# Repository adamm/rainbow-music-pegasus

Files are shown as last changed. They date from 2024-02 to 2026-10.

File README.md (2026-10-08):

# Rainbow Music Pegasus

Disclaimer: This work is a *work-in-progress*.  This project is still under
active development and is estimated to be completed _Spring 2027_.
What you see here is code that is largely incomplete, buggy, probably crashes,
and could catch fire. The PCB board is largely inefficient, expensive,
probably broken, and could catch fire.

## Description

Rainbow Music Pegasus is a combination 3D printed horse coupled with a PCB
with 10 or more RGB lights, microphone, and a MCU.  A
[Fast Fourier transform](https://en.wikipedia.org/wiki/Fast_Fourier_transform)
algorithm translates an audio signal from the microphone, which is displayed
as a flashing colour light display as the horse's wings.

The original design from the horse is from Stlflix, but its internals were
not adequate to support the PCB.  As a result I completely remapped all
vertices, and designed the internal mount to hold the PCB unit vertically.

## Design

The PCB features an ESP32-C3 MCU, a PUI Audio AOM-5024P-HD-MB-R electret
microphone, an OPA2322 dual amplifier with an MCP41050 digital potentiometer,
up to 24 WS2812B RGB LEDs, and an MCP73831 battery charging circuit.  The full schematic is in
[schematic.pdf](schematic.pdf) and the parts list is in [bom.csv](bom.csv).

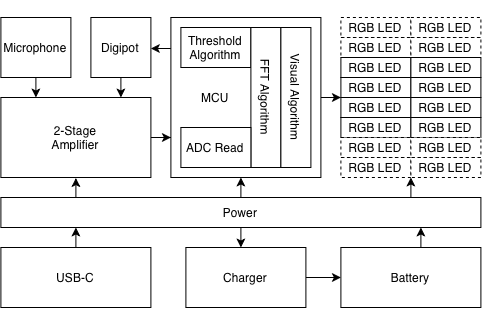
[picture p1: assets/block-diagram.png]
Block Diagram


[View on KiCanvas](https://kicanvas.org/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)

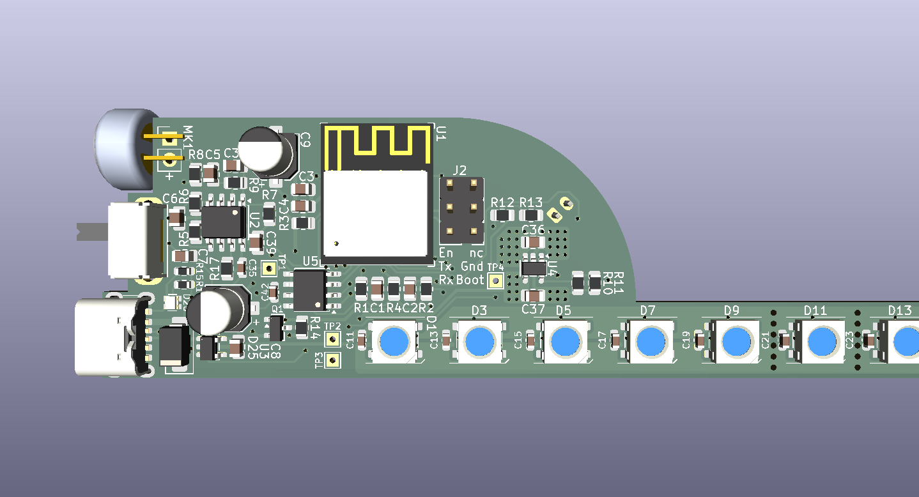
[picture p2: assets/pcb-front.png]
PCB v1.1 Front


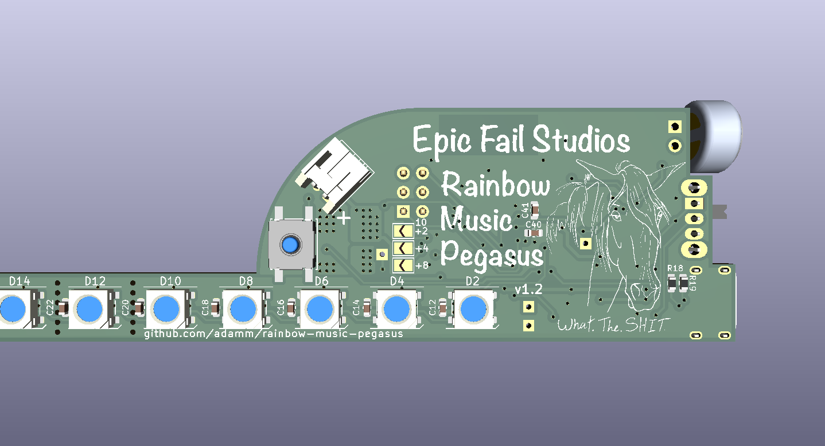
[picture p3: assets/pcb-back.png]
PCB v1.1 Back


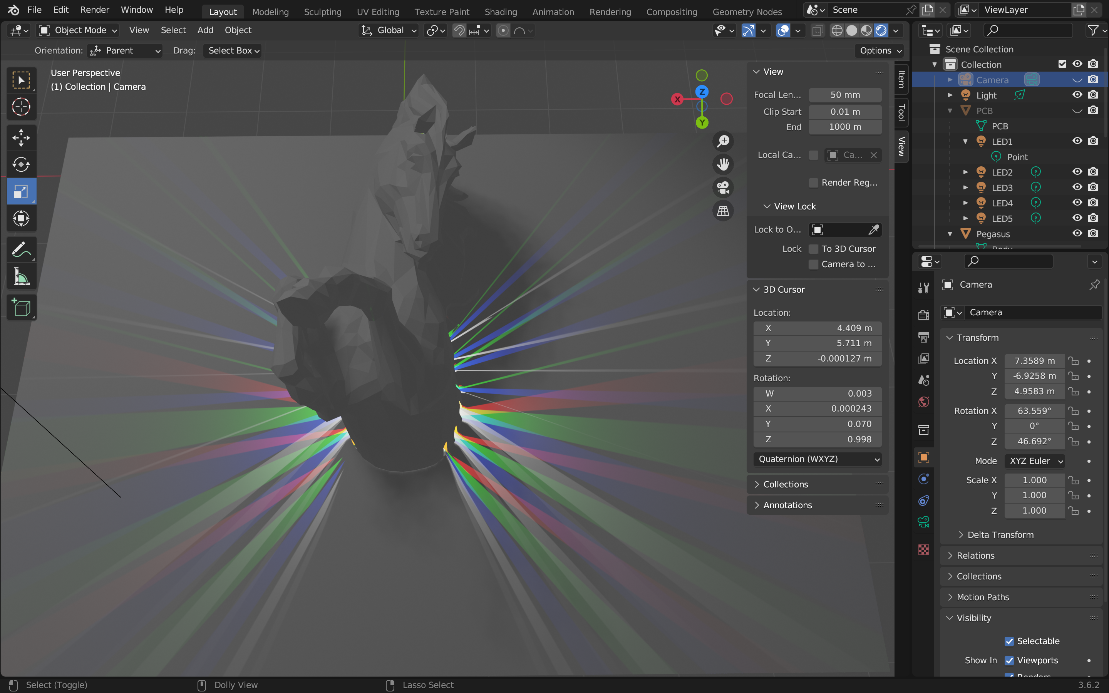
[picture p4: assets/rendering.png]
Rendering


## History

Version 1.0 of the rainbow-music-pegasus was completed March 2024.  A few
test units were sold at Breyer West show, but were never mass produced.
This version lacks wifi, bluetooth, and battery support.

Version 1.1 added a battery and charging module, battery status lights, and adjusting the position of the LEDs.

Version 1.2 is under active development. It will clean up the amp's stage-1
and digipot controlled stage-2, make use of the set-mode button, use USB-C
to charge, and other bug fixes. It is estimated to be completed Spring
2027.

## Battery

Use a single-cell (3.7V nominal) LiPo of 400mAh or larger, connected to the
JST PH connector J3.  The MCP73831 charges at a fixed 200mA (set by R10 and
R11), which keeps the charge rate at or below 0.5C for a 400mAh cell.  Larger
batteries are fine but take longer to charge: roughly 4 hours for 800mAh and
10 hours for 2000mAh.

When the battery runs low (under about 3.6V), the first light in each wing
blinks red every 3 seconds.  The rest of the light show carries on as usual.
The blinking stops once the battery is charging:

- **v1.1**: once charging brings the battery back over 3.7V.
- **v1.2**: within 10 seconds of plugging in USB.  While USB is plugged in,
  v1.2 measures the USB supply rather than the battery.

## Repository layout

| Path | Contents |
|---|---|
| [firmware/](firmware/) | ESP-IDF firmware for the ESP32-C3 (see its [README](firmware/README.md)) |
| [pcb/](pcb/) | KiCad project, 3D models and gerbers |
| [stl/](stl/) | Pegasus model (Blender, STL, 3MF), PCB model and SMT stencil mount (OpenSCAD) |
| [assets/](assets/) | Images used in this README |
| [schematic.pdf](schematic.pdf) | Exported schematic |
| [bom.csv](bom.csv) | Bill of materials |

Clone with submodules to get the Espressif KiCad libraries:

```sh
git clone --recurse-submodules https://github.com/adamm/rainbow-music-pegasus.git
```

## Building the firmware

The firmware uses ESP-IDF v5.x:

```sh
cd firmware
idf.py set-target esp32c3
idf.py build
idf.py -p <PORT> flash monitor
```

See [firmware/README.md](firmware/README.md) for the pin map, the LED-count
jumpers and how the audio pipeline works.

## Mic sensitivity

The microphone's sensitivity adjusts automatically.  If the sound is too
quiet it is turned up, and if it is so loud the wings stay at full
brightness it is turned down.  For 3 seconds after power-on, the wings will
appear to "flap" in white while the sensitivity settles to the room.  When
the device is moved between quiet and loud environments, it takes a few
seconds to catch up.

## Noisy rooms

The wings can show music over the sound of a crowd talking.  The pegasus keeps
learning each room's background sound, and lights up only for sound well
above it, such as the music's beats.  It follows a crowd as it gets louder
or quieter over several seconds.  Anything that holds steady, like a long
note, is learned too and fades away after about 20 seconds.  The music has
to be louder than the crowd, at least on its beats, to show.

## Set Mode

v1.1 has a new "Set Mode" button.  The intention is to flip between LED
animation modes, and to do a factory reset.

*Important*: Development of the button has not yet started but planned to be
ready Spring 2027 as v1.2.

## TODO

- [X] Release v1 for Breyer West 2024
- [X] Listen to music
- [X] Interpret music signal into the light show
- [X] Support a rechargable LiPo battery
- [X] Low battery warning
- [X] Replace USB-mini with USB-C for power
- [ ] Implement "Set Mode" button
- [ ] Add wifi support
- [ ] Add bluetooth support
- [ ] Release v1.2 for Calgary Makerfaire 2027
- [ ] Sync with nearby horses for an enhanced light show
- [ ] Control of colour modes and settings via Web Bluetooth
- [ ] Firmware updates over BLE

## License

See [LICENSE.md](LICENSE.md) (Apache 2.0).

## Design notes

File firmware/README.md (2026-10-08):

# Rainbow Music Pegasus Firmware

ESP-IDF firmware for the Rainbow Music Pegasus board.  It samples the
microphone, runs an FFT, and drives the WS2812B LEDs in the wings with the
result.

## Requirements

- [ESP-IDF](https://docs.espressif.com/projects/esp-idf/en/latest/esp32c3/get-started/)
  v5.x (the project was created with v5.5.1)
- Target: ESP32-C3 only.  Other targets fail to build: the original ESP32
  can't read the mic's ADC in DMA mode, and other models are untested.
- [esp-dsp](https://components.espressif.com/components/espressif/esp-dsp),
  fetched automatically by the IDF Component Manager

## Building and flashing

```sh
. $IDF_PATH/export.sh          # load the ESP-IDF environment
cd firmware
idf.py set-target esp32c3      # only needed the first time
idf.py build
idf.py -p <PORT> flash monitor
```

`<PORT>` is the board's USB serial device, e.g. `/dev/cu.usbmodem*` on macOS
or `/dev/ttyACM0` on Linux.  Exit the monitor with `Ctrl-]`.

## Unit tests

The unit tests in [`test/`](test/) run on your computer, not the board, so
they need only a C compiler and CMake 3.20 or later, not ESP-IDF or hardware.
They use the [Unity](https://github.com/ThrowTheSwitch/Unity) test framework,
which CMake downloads the first time.

```sh
cd firmware
cmake -S test -B test/build
cmake --build test/build
ctest --test-dir test/build --output-on-failure
```

Each `test/test_<module>.c` tests `main/<module>.c`.  The ESP-IDF calls the
firmware makes (GPIO, SPI, ADC, RMT, timer) go to the fakes in `test/fakes/`
instead.  A test uses them to set what the hardware reports, such as jumper
levels, ADC samples or the time, and to check what the firmware sent, such as
digipot wiper codes or LED bytes.  Run one test program, e.g.
`test/build/test_mic`, to see each of its tests by name.

The tests are built with AddressSanitizer and UndefinedBehaviorSanitizer, so
an out-of-bounds access fails a test instead of silently corrupting memory as
it would on the ESP32-C3.  Pass `-DSANITIZE=OFF` to CMake if your compiler
doesn't support them.

## How it works

1. **Configure** (`config.c`): read jumpers JP5–JP7 to decide how many LEDs
   are fitted, and pick the FFT size and sample rate from that and the
   [LED pattern](#led-patterns).
2. **Battery** (`battery.c`): take a first battery reading while the LEDs
   are still dark.
3. **Settle** (`main.c`): for 3 seconds a white "scanning" animation runs
   on the wings while the mic sensitivity and the background floor adjust to
   the room.
4. **Light show** (`main.c`, `leds.c`): forever, read the next half frame of
   mic samples and, with the half before it, remove DC, apply a Blackman
   window and FFT, adjust the mic sensitivity, learn each
   bin's background floor and keep only the sound well above it, apply a
   peak-and-decay filter, and send the bins to the LEDs.  Every 10 seconds,
   check the battery.

The ADC samples the mic in continuous (DMA) mode, at a rate set by the LED
count (see [Frequency range](#frequency-range)), so the sample timing is set
by hardware, not software delays, and other tasks such Bluetooth can't disturb
it.

Each frame overlaps the one before by half, so the LEDs update every half
frame: in pattern A every 3.2 ms with 10 LEDs, up to 7.7 ms with 24, and in
patterns B and C twice that.  Updating only once a frame sampled a held
note's level too slowly to follow quick changes in it, such as close partials
beating, and turned them into a slow flutter.

The driver hands over half a frame at a time and keeps only the newest: if
the FFT and LED update fall behind, older halves are dropped, so the lights
never lag the sound by more than a frame.  After a dropped half, the half kept
from the last frame no longer leads straight into the next, so the next frame
is read whole.

## LED count jumpers

The board supports 10 to 24 LEDs.  Closing a jumper pulls its GPIO low and
adds LEDs on top of the base 10:

| Jumper | GPIO | Adds |
|---|---|---|
| JP7 | 7 | +2 |
| JP6 | 6 | +4 |
| JP5 | 5 | +8 |

The total is capped at 24.  The FFT size follows the LED count: in pattern
A, 64 samples for up to 10 LEDs, 128 for up to 16, and 256 above that.
Patterns B and C use twice those sizes, 128, 256 and 512.

## LED patterns

The strip alternates between the wings: even LEDs (0, 2, 4, ...) are on the
right wing and odd ones on the left, so each pair of LEDs is the same place
on both wings, and LEDs 0 and 1 are nearest the ESP32.  Each of an LED's red,
green and blue channels shows how loud one FFT bin is.  `CONFIG_LEDS_PATTERN`
in [`main/config.h`](main/config.h) picks which bin each channel shows, at
compile time.  The default is C.

- **A**: each pair shows three bins.  The right LED shows them as green, red
  and blue, and the left LED with the channels rotated, as blue, green and
  red.  So the two wings are equally bright but differently coloured.  A tone
  in one bin is red, green or blue, a tone spread over two bins yellow, cyan
  or magenta, and a broad sound white.
- **B**: each channel shows its own bin, six per pair, lowest first: the
  right then the left LED's red, then their green, then their blue.  So each
  pair runs from red to blue, and the wings show alternate bins.
- **C**: each channel shows its own bin.  The lowest third of the bins light
  every LED's red in strip order, the middle third their green, and the top
  third their blue.  So each colour shows a third of the range along the
  wings: at the default top frequency, 0 to 781 Hz is red, 781 to 1563 Hz
  green, and 1563 to 2344 Hz blue.

So patterns B and C show twice as many bins as A, three per LED rather than
three per pair.  With 24 LEDs, the first pair shows:

| Pattern | Bins shown | LED 0 (right) red, green, blue | LED 1 (left) red, green, blue |
|---|---|---|---|
| A | 36 | bins 1, 0, 2 | bins 2, 1, 0 |
| B | 72 | bins 0, 2, 4 | bins 1, 3, 5 |
| C | 72 | bins 0, 24, 48 | bins 1, 25, 49 |

## Frequency range

Every board and pattern shows the same range, from 0 Hz up to
`CONFIG_LEDS_TOP_FREQ_HZ` (2344 Hz) in [`main/config.h`](main/config.h).  It's
shared equally between the bins the LEDs show, so more LEDs, and patterns B
and C, show it in finer steps.

The LEDs show the lowest LEDs * 3 / 2 bins in pattern A, and the lowest
LEDs * 3 in patterns B and C.  A bin is the sample rate divided by the FFT size
wide, so `config_init()` picks the sample rate that makes those bins end at the
top frequency:

    sample rate = FFT size * top frequency / bins shown

Patterns B and C show twice as many bins with twice the FFT size, so they
sample at the same rate as A.  Their bins are half as wide, but each frame
takes twice as long to sample, so the LEDs update half as often, every half
frame.

| LEDs | Sample rate | FFT size (A / B, C) | Bin width (A / B, C) | Frame (A / B, C) |
|---|---|---|---|---|
| 10 | 10.0 kHz | 64 / 128 | 156 / 78 Hz | 6.4 / 12.8 ms |
| 12 | 16.7 kHz | 128 / 256 | 130 / 65 Hz | 7.7 / 15.4 ms |
| 14 | 14.3 kHz | 128 / 256 | 112 / 56 Hz | 9.0 / 17.9 ms |
| 16 | 12.5 kHz | 128 / 256 | 98 / 49 Hz | 10.2 / 20.5 ms |
| 18 | 22.2 kHz | 256 / 512 | 87 / 43 Hz | 11.5 / 23.0 ms |
| 20 | 20.0 kHz | 256 / 512 | 78 / 39 Hz | 12.8 / 25.6 ms |
| 22 | 18.2 kHz | 256 / 512 | 71 / 36 Hz | 14.1 / 28.2 ms |
| 24 | 16.7 kHz | 256 / 512 | 65 / 33 Hz | 15.4 / 30.7 ms |

The sample rate is always more than four times the top frequency.  Sound
above half the sample rate folds back onto lower bins, and the mic's
anti-aliasing filters (R17 and C41 at 4.8 kHz, R9 and C38 at 10.6 kHz) cut
cymbals and other treble near 10 kHz by only about 10 dB.  A faster rate
folds back only higher sound, which the filters cut more.

Raise the top frequency to show more of the treble, or lower it to show more
detail in the bass.  Much above 4 kHz, the anti-aliasing filter dims the
highest LEDs.  The ADC can't sample faster than 83.3 kHz, which an 18-LED
board reaches at a top frequency of about 8.8 kHz.  The unit tests fail if any
board would need a rate outside the ADC's range.

## Pin map (ESP32-C3)

All pins are defined in [`main/config.h`](main/config.h).

| Function | GPIO | Direction |
|---|---|---|
| Battery (ADC1 channel 0) | 0 | Input |
| Button | 1 | Input |
| WS2812B data | 3 | Output |
| Microphone (ADC1 channel 4) | 4 | Input |
| LED-count jumpers | 5, 6, 7 | Input  |
| ESP32 Bootloader mode | 9 | Input |
| Digipot MOSI | 10 | Output |
| Digipot CS | 18 | Output |
| Digipot CLK | 19 | Output |
| Serial RXD / Code Upload | 20 | Input |
| Serial TXD / Activity Log | 21 | Output | 

## Source layout

| File | Purpose |
|---|---|
| `main.c` | Startup and the main sample → FFT → LED loop |
| `config.c/h` | Pin assignments, jumper-based LED count, LED pattern, FFT size, sample rate and top frequency |
| `mic.c/h` | Continuous (DMA) sampling of the microphone, with ADC calibration, and automatic mic sensitivity |
| `battery.c/h` | Battery voltage readings, smoothing, and the low-battery decision |
| `fft.c/h` | Fixed-point FFT of each frame: DC removal, Blackman window, FFT and bin levels in mV.  The ESP32-C3 has no FPU, so integer maths is much faster |
| `leds.c/h` | WS2812B output over RMT in each LED pattern, startup scanning animation, low-battery blink |
| `led_strip_encoder.c/h` | RMT encoder for WS2812B (from the ESP-IDF examples) |
| `digipot.c/h` | SPI driver for the MCP41050 digital potentiometer |

## Mic sensitivity

The MCP41050's B–W resistance is the feedback resistor of the second op-amp
stage (U2B), so the preamp gain is proportional to it.  Wiper code 00h is at
terminal B, so a higher wiper code means higher gain.  `mic.c` uses the
wiper code (0 to 255) directly as the sensitivity.

After every frame's FFT, `main.c` looks at the loudest bin the LEDs show and
tells `mic_sensitivity_update()` whether the frame was too loud or too quiet:

- If the brightest LED stays at full brightness, or the samples keep clipping
  near the ADC rails, for 50 ms, the sensitivity drops by a quarter (about
  -2.5 dB).
- If the loudest bin stays under a quarter of full brightness for 200 ms, the
  sensitivity rises by an eighth (about +1 dB).

The steps repeat while the condition lasts, so after moving to a louder or
quieter room the lights recover within a few seconds.

Each FFT bin is converted to millivolts at the ADC, so the LEDs behave the same
whatever the frame size.  Bins under `FFT_NOISE_FLOOR_MV` in `main.c` are
always dark, and bins at `FFT_FULL_SCALE_MV` light at full brightness.
Raising full scale makes the sensitivity settle higher, using more of the
ADC's range, as long as the signal doesn't clip.  The clipping limits and hold
times are `#define`s at the top of `mic.c`.

## Background sound

To show music over a noisy room, such as a crowd talking, `main.c` learns the
level of each FFT bin's background sound, its floor, and lights a bin only
once it's 12 dB (4 times) over that.  The floor is learned all the time,
and follows a crowd as it grows or thins.

- While a bin is louder than its floor, the floor rises by 1 dB a second.
  While it's quieter, the floor falls by 3 dB a second.  So the floor settles
  where the bin is quieter than it a quarter of the time.
- A crowd never goes quiet, so the floor sits on it.  Beats are loud for much
  less than three quarters of the time, so the floor stays under them and
  they stand out.
- Noise in a bin jumps around from frame to frame, and gets 12 dB over its
  quietest quarter in 1 to 2% of frames.  So a steady crowd still lights an
  LED dimly now and then.
- Anything that doesn't change is learned too, so a note held 20 dB over the
  threshold fades out in about 20 seconds.  The light show follows beats and
  changes more than steady sound.
- A bin's brightness runs from its threshold up to full scale, so music over
  a noisy room can still reach full brightness.  Beats 12 dB over a crowd's
  average level show at about a quarter of full brightness.
- In a quiet room the floor falls until the threshold is `FFT_NOISE_FLOOR_MV`,
  and stops there, so hiss stays dark and a new crowd is learned from there.
- During the 3-second settling period the floor learns 15 times faster, so it
  can climb 45 dB and the light show starts with the room already learned.
- When the mic sensitivity changes, `mic_sensitivity_update()` returns the
  change in gain, and the floor is scaled by it to stay in step with the
  sound.

Music has to be louder than the crowd, at least on its beats, to show: with
one microphone, sound no louder than the crowd can't be told apart from it.
Someone talking right next to the pegasus isn't learned either, because
speech has pauses.

The rates, margin and speed-up are the `FLOOR_` `#define`s at the top of
`main.c`.

## Battery level

R12 and R13 (100k each) halve the battery voltage at GPIO 0, so a full 4.2 V
battery reads 2.1 V.  `battery.c` averages 16 oneshot ADC readings and
doubles the result.

The mic and the battery are both on ADC1, which can sample continuously or
take oneshot readings but not both at once.  So `main.c` takes the first
reading at power-on, before the mic starts.  After that, every 10 seconds it
pauses the mic (`mic_pause()`), reads the battery and resumes the mic
(`mic_resume()`).  Resuming drops what the ADC recorded before the pause, and
the next frame is read whole, so this delays the next update by up to a frame
(15.4 ms in pattern A, 30.7 ms in B and C).

The voltage dips with the music as the LEDs draw current, so readings are
smoothed.  The smoothed voltage moves about two thirds of the way to a new
reading over 30 seconds.  The first reading is taken as is, because the LEDs
are still dark.  The battery is low once the smoothed voltage is under
3.6 V.  It stays low until the voltage is back over 3.7 V, so the warning
doesn't flicker on and off around 3.6 V.  The LEDs and ESP32-C3 run from a
3.3 V regulator, which starts to drop out with the battery under about 3.4 V.

While the battery is low, the first LED in each wing (the first pair on the
strip, nearest the ESP32) blinks red for a quarter of a second every 3
seconds.  It shows the music the rest of the time, and the other LEDs aren't
affected.  In pattern A the light show can't make both LEDs of a pair pure
red, so the blink can't be mistaken for music.  In patterns B and C it can,
when bass lights only the lowest two bins.

What GPIO 0 measures depends on the board:

- **v1.1**: the divider is wired straight to the battery, so it always reads
  the battery, even while USB charges it.  The warning stops once charging
  brings the battery back over 3.7 V.
- **v1.2**: the divider is after the power switch, so it doesn't drain the
  battery while the switch is off.  While USB is plugged in it reads the USB
  supply, about 4.6 V after D25, instead of the battery.  The warning stops at
  the next check after USB is plugged in.

The thresholds, smoothing time and number of samples are `#define`s at the
top of `battery.c`.  The check interval is in `main.c`, and the blink's
timing and brightness are in `leds.c`.

## Logs

Useful messages appear in the serial monitor:

- `config`: which jumpers are closed, the LED count, the LED pattern and how
  many bins it shows, the FFT size and the sample rate
- `battery`: each reading, e.g. `3712 mV, smoothed 3698 mV`, and when the
  battery becomes low or stops being low
- `main`: start and finish of the 3-second settling period, and each second,
  how many of the shown bins' background floors went up or down by more than
  0.5 dB, e.g. `adjusted the floor up on 3 bins and down on 1, of 15`.  Gain
  changes aren't counted, since `mic` logs those.  In a steady room most bins
  stay put; when a crowd grows or a note is held, they go up.
- `main`, each second of the light show: how many frames it processed, how
  long each lasts and how far apart they are (half a frame), how many halves
  of a frame the mic dropped because the frame before was still being
  processed, and how long a frame took to process, on average and at most.  The average is split into steps: reading the samples (converting them
  to mV, not waiting for them), the window (with removing DC), the FFT, the
  magnitudes, and the rest (the floor, the colours, sending them to the LEDs,
  the battery check and logging).  The light show keeps up while a frame takes
  less time to process than half a frame takes to record.  Once it doesn't,
  the mic drops halves of frames, and the LEDs miss that sound.
- `mic`: each sensitivity change, e.g. `too quiet, sensitivity 128 -> 144`

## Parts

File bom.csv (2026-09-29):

Reference | Value | Footprint | Description | Quantity
C1, C2, C4 | 0.1uF | Capacitor_SMD:C_0805_2012Metric |  | 3
C3 | 10uF | Capacitor_SMD:C_0805_2012Metric |  | 1
C5, C6, C8, C39 | 2.2uF | Capacitor_SMD:C_0805_2012Metric |  | 4
C7 | 1.0uF | Capacitor_SMD:C_0805_2012Metric |  | 1
C9, C10 | 220uF | Capacitor_SMD:CP_Elec_5x5.9 |  | 2
C11-C35, C40-C42 | 0.1uF | Capacitor_SMD:C_0603_1608Metric | Place C41 by GPIO4 | 28
C36, C37 | 4.7uF | Capacitor_SMD:C_0805_2012Metric |  | 2
C38 | 6.8nF C0G | Capacitor_SMD:C_0805_2012Metric |  | 1
D1-D24 | WS2812B | LED_SMD:LED_WS2812B_PLCC4_5.0x5.0mm_P3.2mm |  | 24
D25 | CDBA540 | Diode_SMD:D_SMA |  | 1
D26 | LTST-C195KGJRKT | Altivo:LTST-C195KGJRKT | LED dual red/green, 4-pin | 1
J1 | USB4125-GF-A-0190 | Altivo:USB_C_Receptacle_GCT_USB4125-xx-x-0190_6P_TopMnt_Horizontal | USB Power-Only 6P Type-C Receptacle connector | 1
J3 | S2B-PH-K-S | Connector_JST:JST_PH_S2B-PH-K_1x02_P2.00mm_Horizontal |  | 1
MK1 | AOM-5024P-HD-MB-R | Connector_PinHeader_2.54mm:PinHeader_1x02_P2.54mm_Vertical |  | 1
Q1 | DMG3415U | Package_TO_SOT_SMD:SOT-23 |  | 1
R1-R6, R10, R11 | 10k | Resistor_SMD:R_0805_2012Metric |  | 8
R7-R9 | 2.2k | Resistor_SMD:R_0805_2012Metric |  | 3
R12-R14 | 100k | Resistor_SMD:R_0805_2012Metric |  | 3
R15, R16 | 470 | Resistor_SMD:R_0603_1608Metric |  | 2
R17 | 330 | Resistor_SMD:R_0805_2012Metric |  | 1
R18, R19 | 5.1k | Resistor_SMD:R_0603_1608Metric |  | 2
SW1 | SW_SPDT | Button_Switch_THT:SW_Slide_SPDT_Angled_CK_OS102011MA1Q |  | 1
SW2 | EVQQ2 | Button_Switch_SMD:SW_SPST_EVQQ2 |  | 1
U1 | ESP32-C3-MINI-1 | PCM_Espressif:ESP32-C3-MINI-1 |  | 1
U2 | OPA2322 | Package_SO:SOIC-8_3.9x4.9mm_P1.27mm |  | 1
U3 | TLV75533PDBV | Package_TO_SOT_SMD:SOT-23-5 |  | 1
U4 | MCP73831-2-OT | Package_TO_SOT_SMD:SOT-23-5 |  | 1
U5 | MCP41050 | Package_SO:SOIC-8_3.9x4.9mm_P1.27mm |  | 1

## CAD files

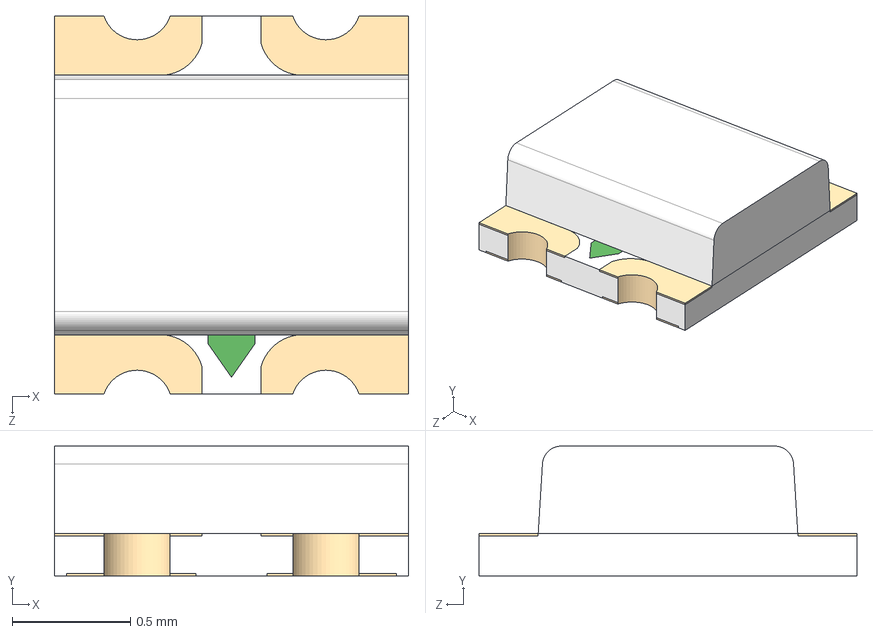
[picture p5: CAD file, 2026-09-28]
pcb/3d/LTST-C195KGJRKT.step
1.50 x 0.55 x 1.60 mm

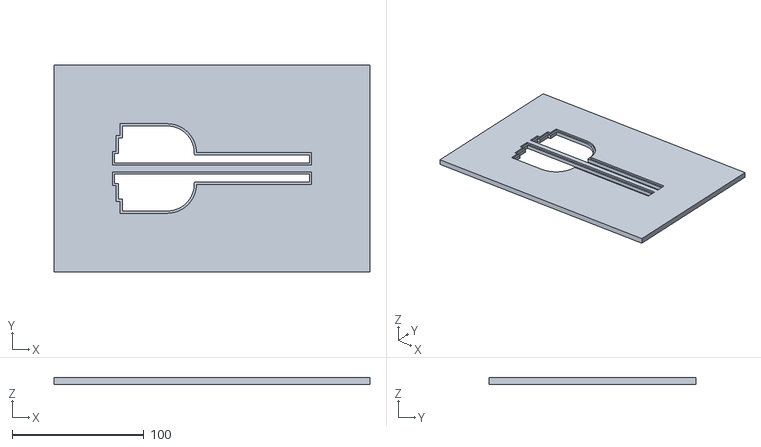
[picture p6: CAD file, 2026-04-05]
stl/stencil-mount.stl
240.0 x 157.0 x 5.00

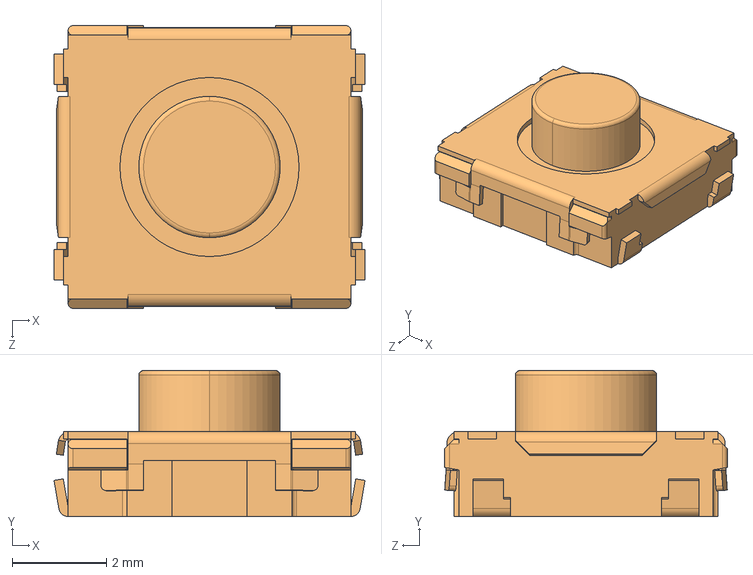
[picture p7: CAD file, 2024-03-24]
pcb/3d/evqq2-bfkpuy-03w_.step
6.60 x 3.10 x 6.00 mm

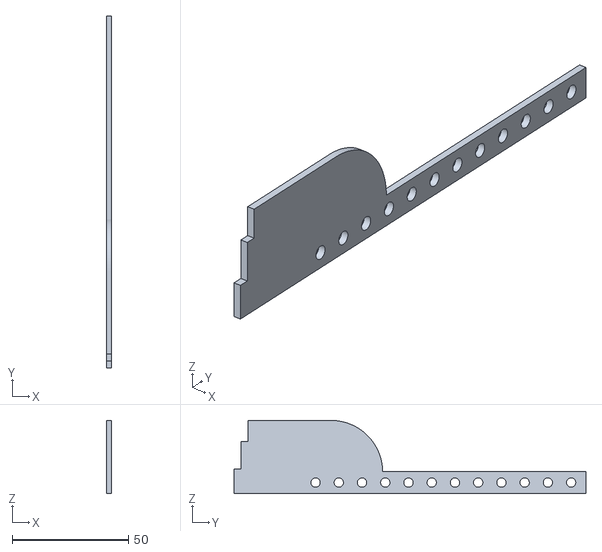
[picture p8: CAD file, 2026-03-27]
stl/pcb.stl
2.20 x 151.5 x 31.5

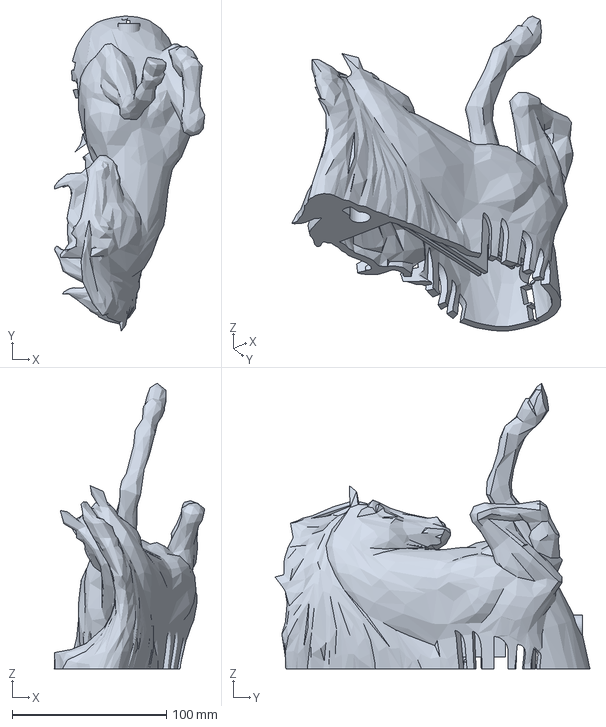
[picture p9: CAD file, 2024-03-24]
stl/pegasus.3mf
97.5 x 204.1 x 185.0 mm

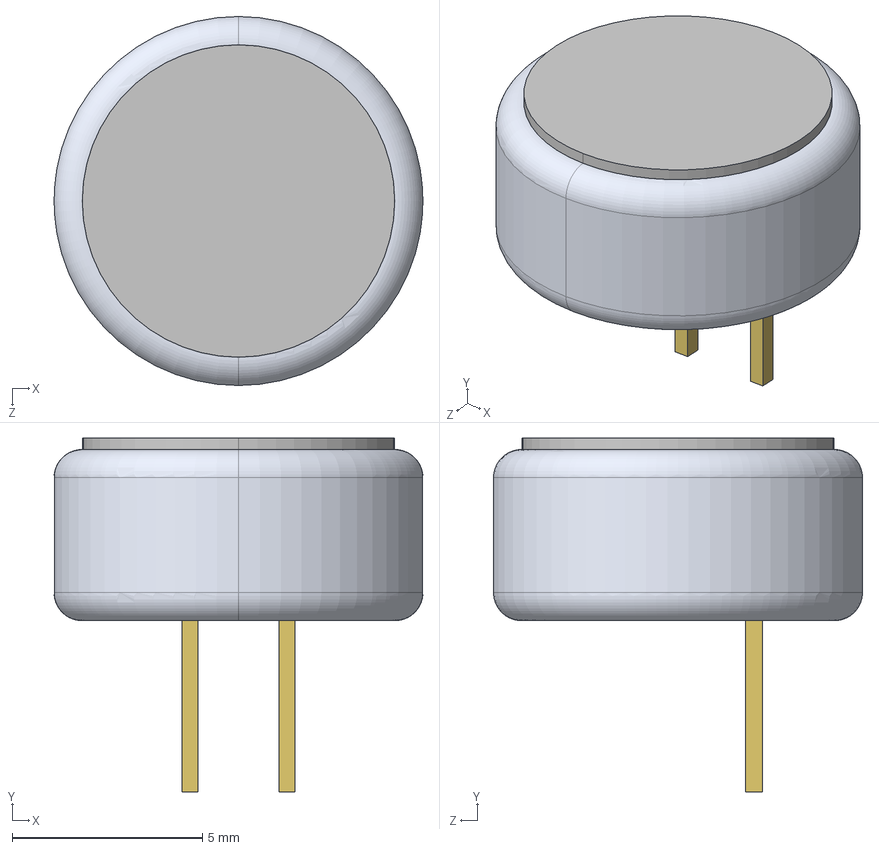
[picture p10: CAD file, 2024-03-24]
pcb/3d/CMA-4544PF-W.stp
9.69 x 9.30 x 9.70 mm

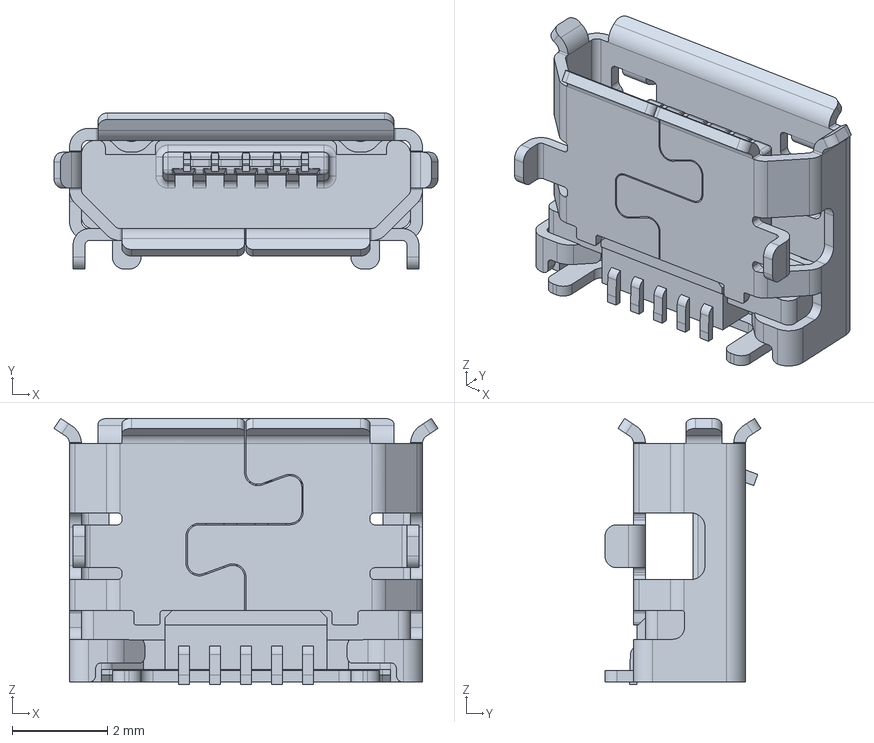
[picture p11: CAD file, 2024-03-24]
pcb/3d/10118194-0001LF.stp
8.05 x 3.27 x 5.58 mm

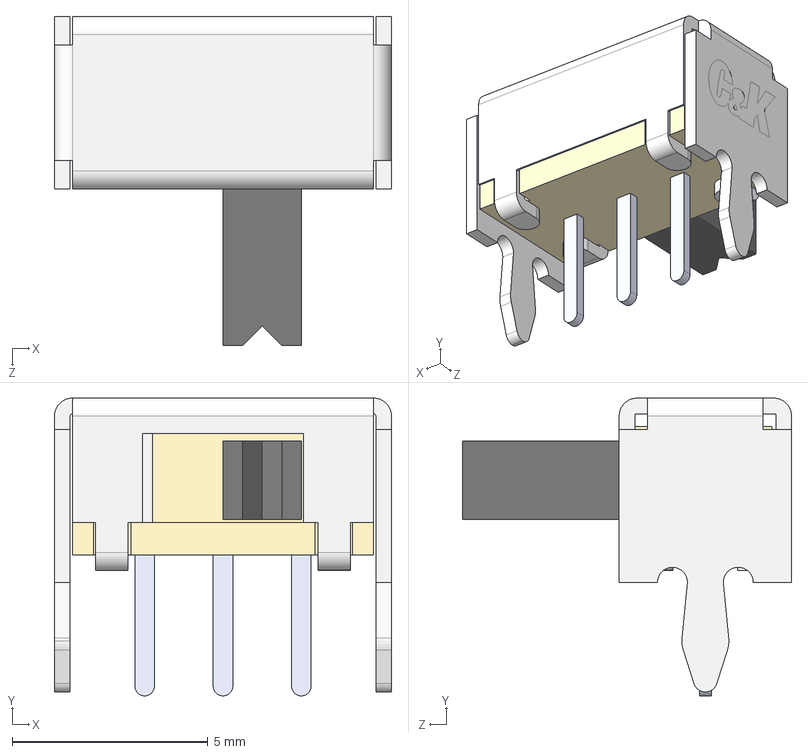
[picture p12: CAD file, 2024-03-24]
pcb/3d/OS102011MA1QN1.stp
8.60 x 7.60 x 8.40 mm
knob
cover
inside
pins

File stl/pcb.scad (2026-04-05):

$fn = 100;
pcb_w = 151;
pcb_l = 31;
pcb_h = 1.6;

rgb_x = 34.8525;
rgb_y = 4.5;
rgb_z = 1;
rgb_l = 9;
rgb_w = 10;
rgb_h = 2;

module microphone() {
    translate([20.0, pcb_l-3.0, 0.8])
        rotate([0,90,180])
            cylinder(27, 5.5, 5.5, false);
}

module switch() {
    translate([-4, 10.5, pcb_h-0.1])
        cube([13, 10.5, 5], false);
}

module usb() {
    translate([-4, 0.6, pcb_h-0.5])
        cube([13, 8.75, 3.5], false);
}

module led(x) {
    translate([rgb_x+x, rgb_y, rgb_z]) {
        cylinder(3, 2, 2, true);
    }
}

module holes(x) {
    translate([10.3333, pcb_l-6, -1]) {
        cylinder(4, 1.2, 1.2);
    }
    translate([37.8333, pcb_l-6, -1]) {
        cylinder(4, 1.2, 1.2);
    }
}

module pcb(draw_holes=true) {
    //translate([0, 0, -pcb_h/2])
    difference() {
        linear_extrude(height=pcb_h) {
            // Add 0.25mm to all ends to better align with
            // 3d printer tolerance
            offset(delta=+0.25) {
                polygon(points=[[0,0], [0, 10], [3, 10], [3, 22], [6,22], [6, pcb_l], [10, pcb_l],
                [41.5, pcb_l], [41.5, rgb_l], [pcb_w, rgb_l],
                [pcb_w, 0]
                ]);
                translate([41.5, 9, 0]) {
                    intersection() {
                        square(22);
                        circle(r=22);
                    }
                }
            }
        }
        if (draw_holes) {
            led(0);
            led(10);
            led(20);
            led(30);
            led(40);
            led(50);
            led(60);
            led(70);
            led(80);
            led(90);
            led(100);
            led(110);
        }
    }
}

rotate([90, 0, 90]) {
    union() {
        //microphone();
        //switch();
        //usb();
        //pcb(true);
    }
}

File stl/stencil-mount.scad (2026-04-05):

include <pcb.scad>;

margin_w = 30;
margin_l = 30;

stencil_w = 210;
stencil_l = 127;
stencil_h = 0.0;

board_w = stencil_w + margin_w;
board_l = stencil_l + margin_l;
board_h = 5.0;

board_x = pcb_w/2 - board_w/2;
board_y = -board_l/2;
board_z = 0;

stencil_x = -margin_w;
stencil_y = -(board_l/2) + margin_l/2;
stencil_z = board_h - stencil_h;

module negative_pcb(x, y, z) {
    translate([x, y, board_h-stencil_h-pcb_h]) //pcb(false);
        linear_extrude(height=board_h+3)
            projection(cut=true)
                pcb(false);
    translate([x, y, -0.01])
        linear_extrude(height=board_h+3)
            offset(delta=-1.75)
                projection(cut=true)
                    pcb(false);
}

module board() {
    difference() {
        translate([board_x, board_y, board_z])
            cube([board_w, board_l, board_h]);
        negative_pcb(0, 2.75, 0);
        mirror([0,1,0])
            negative_pcb(0, 2.75, 0);

        if (stencil_h > 0) {
            // Trim the stencil area
            translate([stencil_x, stencil_y, stencil_z])
                cube([stencil_w, stencil_l, stencil_h+4]);

            // Create a tab for lifting the stencil
            translate([stencil_w/2-pcb_w/2, stencil_y-margin_l, stencil_z])
               cube([stencil_w/4, stencil_l+margin_l*2, stencil_h+4]);
        }
    }
}

board();

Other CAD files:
stl/pegasus-extruded.blend
stl/pegasus.blend
stl/pegasus.stl

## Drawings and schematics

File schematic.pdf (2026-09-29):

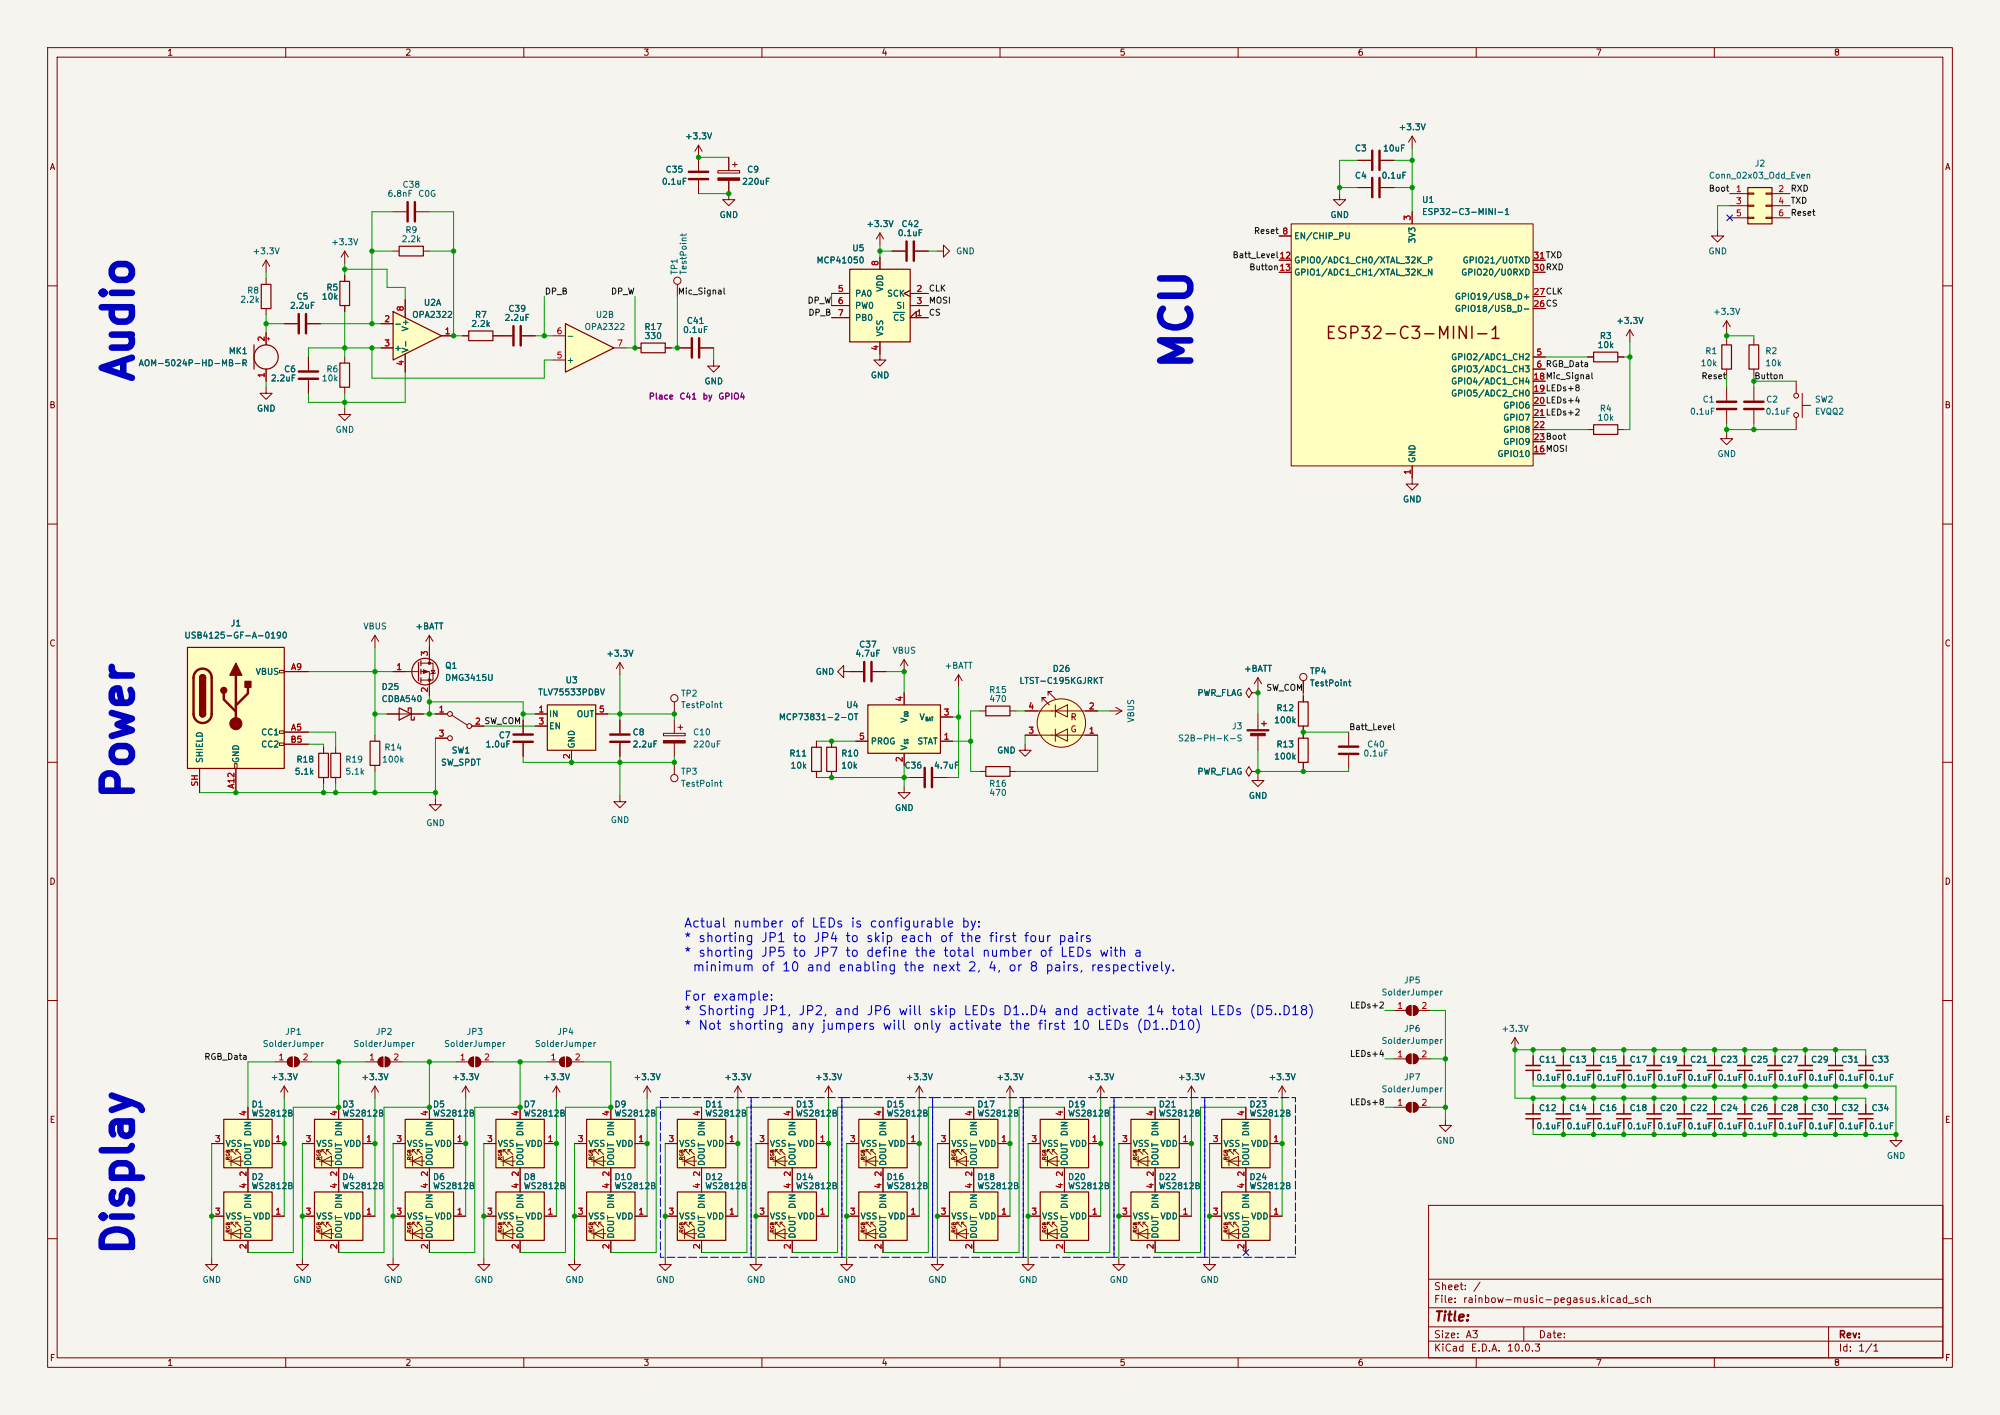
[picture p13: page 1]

* Not shorting any jumpers will only activate the first 10 LEDs (D1..D10) Power

Actual number of LEDs is configurable by:
* shorting JP1 to JP4 to skip each of the first four pairs
* shorting JP5 to JP7 to define the total number of LEDs with a minimum of 10 and enabling the next 2, 4, or 8 pairs, respectively.

For example:
* Shorting JP1, JP2, and JP6 will skip LEDs D1..D4 and activate 14 total LEDs (D5..D18)

4 D14 WS2812B +3.3V GND GND RGB VDD 1 DOUT 2

File: rainbow-music-pegasus.kicad_sch
Title:

Size: A3 | Rev:
KiCad E.D.A. 10.0.3 | Id: 1/1 | F Date:

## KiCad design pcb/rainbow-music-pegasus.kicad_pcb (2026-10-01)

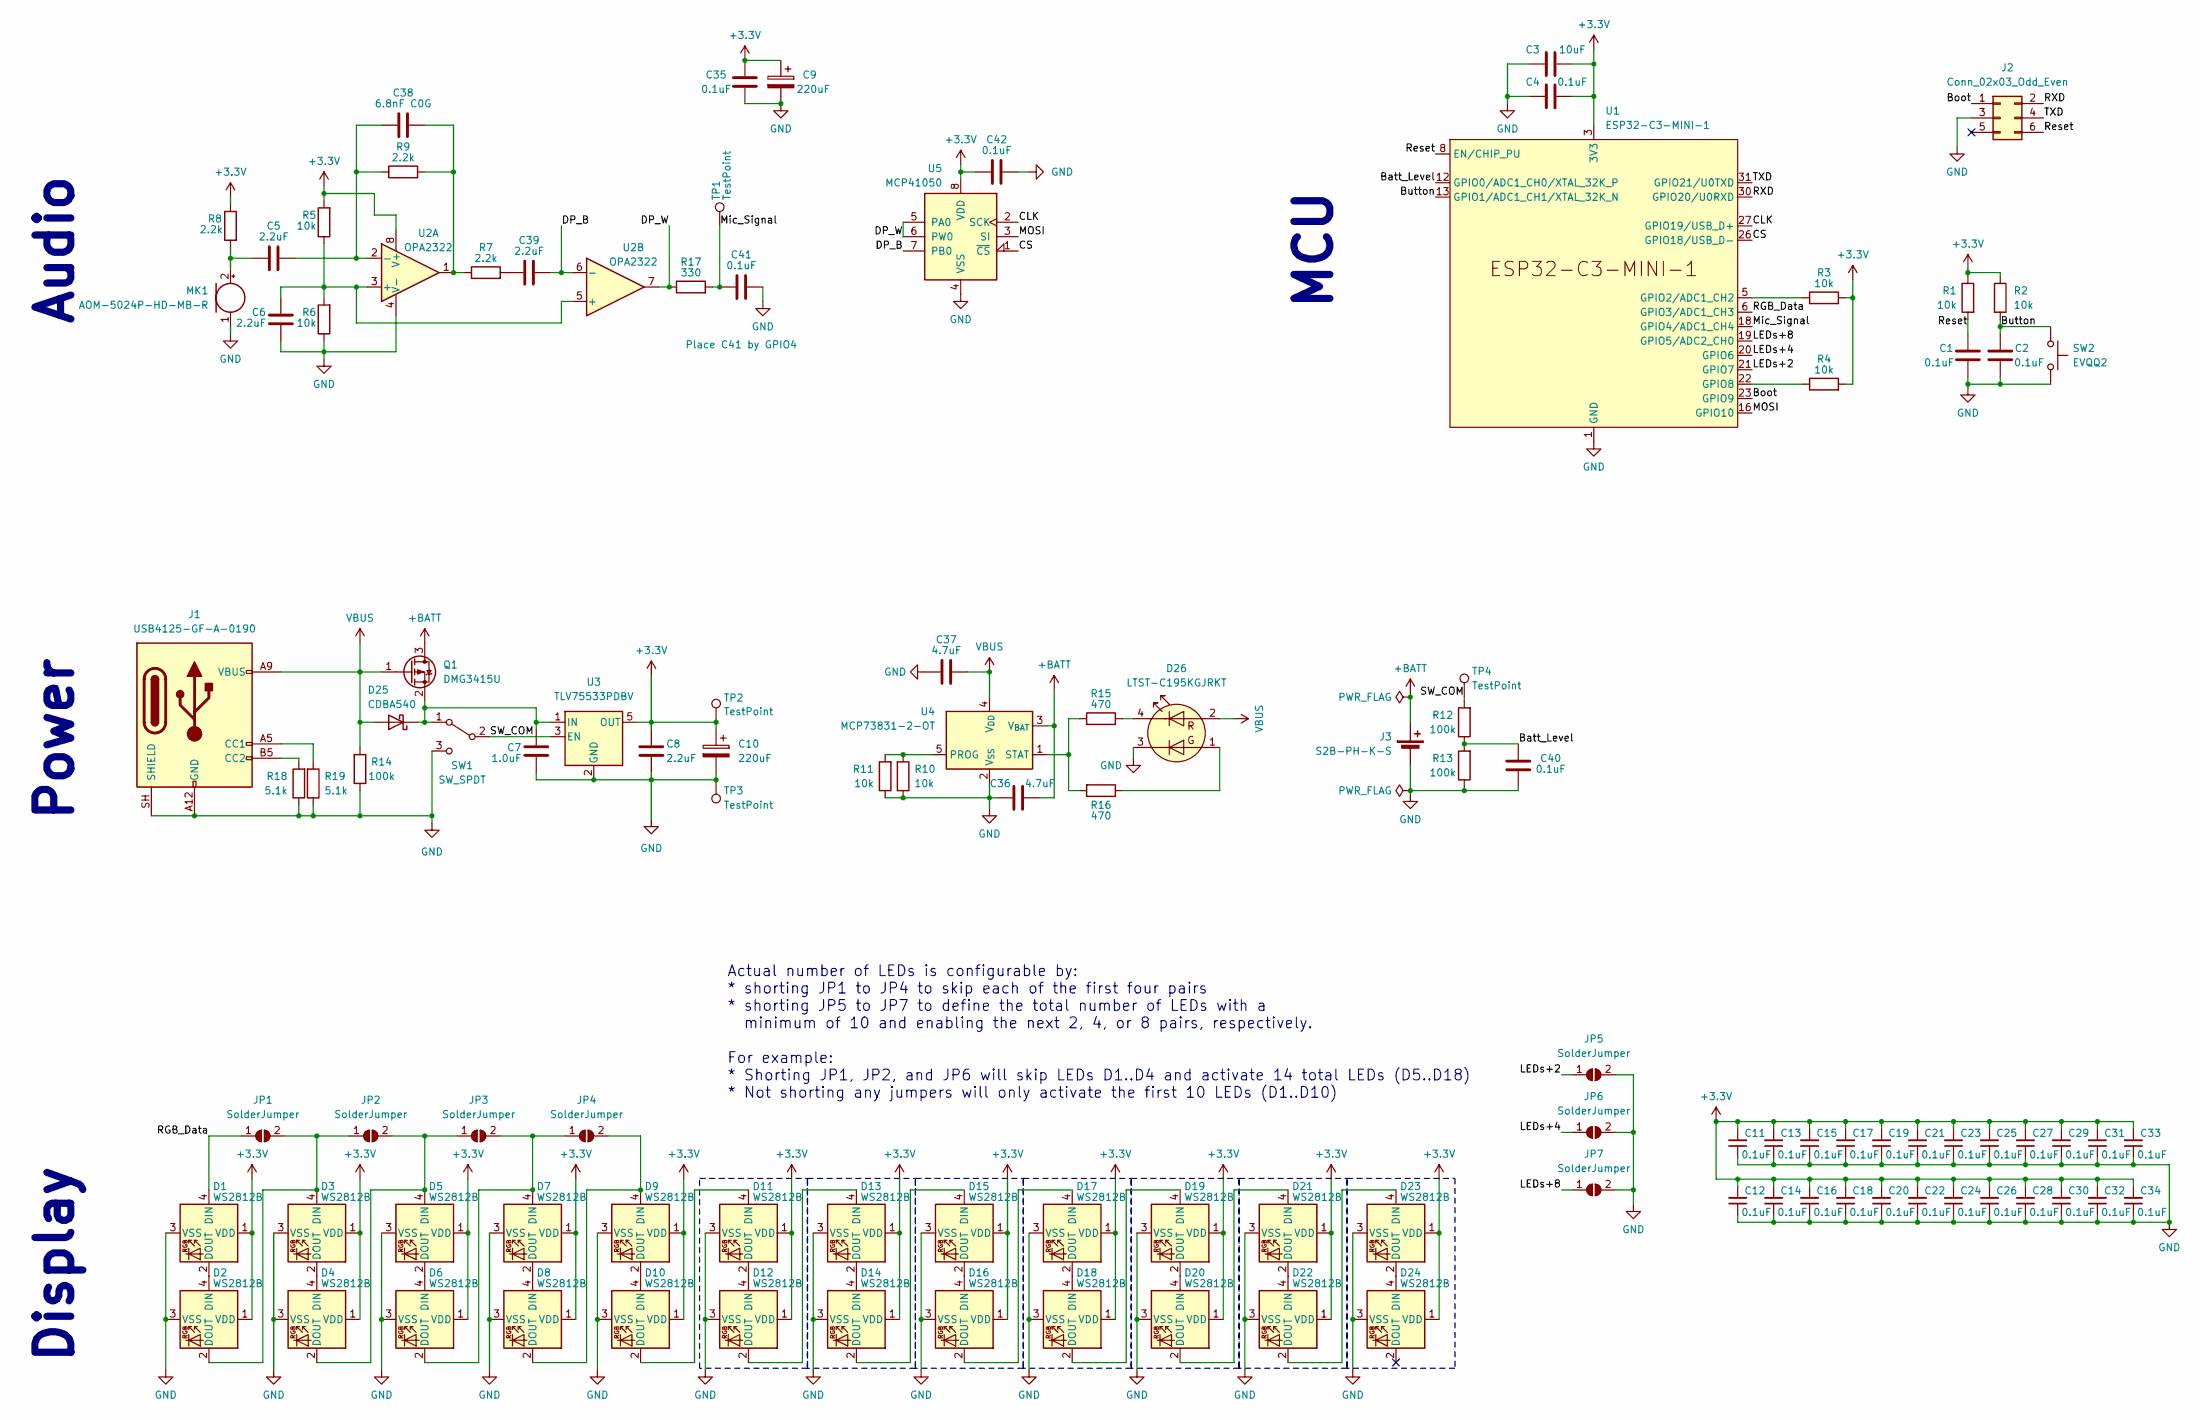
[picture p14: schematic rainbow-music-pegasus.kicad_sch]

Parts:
C1, C2, C4: 0.1uF; C_0805_2012Metric
C3: 10uF; C_0805_2012Metric
C5, C6, C8, C39: 2.2uF; C_0805_2012Metric
C7: 1.0uF; C_0805_2012Metric
C9, C10: 220uF; CP_Elec_5x5.9
C11, C12, C13, C14, C15, C16, C17, C18, C19, C20, C21, C22, C23, C24, C25, C26, C27, C28, C29, C30, C31, C32, C33, C34, C35, C40, C41, C42: 0.1uF; C_0603_1608Metric
C36, C37: 4.7uF; C_0805_2012Metric
C38: 6.8nF C0G; C_0805_2012Metric
D1, D2, D3, D4, D5, D6, D7, D8, D9, D10, D11, D12, D13, D14, D15, D16, D17, D18, D19, D20, D21, D22, D23, D24: WS2812B; LED_WS2812B_PLCC4_5.0x5.0mm_P3.2mm
D25: CDBA540; D_SMA
D26: LTST-C195KGJRKT
J1: USB4125-GF-A-0190; USB_C_Receptacle_GCT_USB4125-xx-x-0190_6P_TopMnt_Horizontal
J2: Conn_02x03_Odd_Even; PinHeader_2x03_P2.54mm_Vertical
J3: S2B-PH-K-S; JST_PH_S2B-PH-K_1x02_P2.00mm_Horizontal
JP1, JP2, JP3, JP4, JP5, JP6, JP7: SolderJumper; SolderJumper-2_P1.3mm_Open_TrianglePad1.0x1.5mm
MK1: AOM-5024P-HD-MB-R; PinHeader_1x02_P2.54mm_Vertical
Q1: DMG3415U; SOT-23
R1, R2, R3, R4, R5, R6, R10, R11: 10k; R_0805_2012Metric
R7, R8, R9: 2.2k; R_0805_2012Metric
R12, R13, R14: 100k; R_0805_2012Metric
R15, R16: 470; R_0603_1608Metric
R17: 330; R_0805_2012Metric
R18, R19: 5.1k; R_0603_1608Metric
SW1: SW_SPDT; SW_Slide_SPDT_Angled_CK_OS102011MA1Q
SW2: EVQQ2; SW_SPST_EVQQ2
TP1, TP2, TP3, TP4: TestPoint; TestPoint_THTPad_1.5x1.5mm_Drill0.7mm
U1: ESP32-C3-MINI-1
U2: OPA2322; SOIC-8_3.9x4.9mm_P1.27mm
U3: TLV75533PDBV; SOT-23-5
U4: MCP73831-2-OT; SOT-23-5
U5: MCP41050; SOIC-8_3.9x4.9mm_P1.27mm

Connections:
+3.3V: C3.2, C4.2, C8.2, C9.1, C10.1, C11.2, C12.2, C13.2, C14.2, C15.2, C16.2, C17.2, C18.2, C19.2, C20.2, C21.2, C22.2, C23.2, C24.2, C25.2, C26.2, C27.2, C28.2, C29.2, C30.2, C31.2, C32.2, C33.2, C34.2, C35.2, C42.1, D1.1 (VDD), D2.1 (VDD), D3.1 (VDD), D4.1 (VDD), D5.1 (VDD), D6.1 (VDD), D7.1 (VDD), D8.1 (VDD), D9.1 (VDD), D10.1 (VDD), D11.1 (VDD), D12.1 (VDD), D13.1 (VDD), D14.1 (VDD), D15.1 (VDD), D16.1 (VDD), D17.1 (VDD), D18.1 (VDD), D19.1 (VDD), D20.1 (VDD), D21.1 (VDD), D22.1 (VDD), D23.1 (VDD), D24.1 (VDD), R1.1, R2.1, R3.2, R4.2, R5.2, R8.1, TP2.1 (1_1), U1.3 (3V3), U2.8 (V+), U3.5 (OUT), U5.8 (VDD)
+BATT: C36.2, J3.1 (+), Q1.3 (D), U4.3 (V_{BAT})
/Batt_Level: C40.1, R12.1, R13.2, U1.12 (GPIO0/ADC1_CH0/XTAL_32K_P)
/Boot: J2.1, U1.23 (GPIO9)
/Button: C2.2, R2.2, SW2.1, U1.13 (GPIO1/ADC1_CH1/XTAL_32K_N)
/CLK: U1.27 (GPIO19/USB_D+), U5.2 (SCK)
/CS: U1.26 (GPIO18/USB_D-), U5.1 (~CS)
/DP_B: C39.2, U2.6 (-), U5.7 (PB0)
/DP_W: R17.1, U2.7, U5.5 (PA0), U5.6 (PW0)
/LEDs+2: JP5.1 (A), U1.21 (GPIO7)
/LEDs+4: JP6.1 (A), U1.20 (GPIO6)
/LEDs+8: JP7.1 (A), U1.19 (GPIO5/ADC2_CH0)
/MOSI: U1.16 (GPIO10), U5.3 (SI)
/Mic_Signal: C41.1, R17.2, TP1.1 (1_1), U1.18 (GPIO4/ADC1_CH4)
/RGB_Data: D1.4 (DIN), JP1.1 (A), U1.6 (GPIO3/ADC1_CH3)
/RXD: J2.2, U1.30 (GPIO20/U0RXD)
/Reset: C1.2, J2.6, R1.2, U1.8 (EN/CHIP_PU)
/SW_COM: R12.2, SW1.2 (B), TP4.1 (1_1), U3.3 (EN)
/TXD: J2.4, U1.31 (GPIO21/U0TXD)
GND: C1.1, C2.1, C3.1, C4.1, C6.1, C7.1, C8.1, C9.2, C10.2, C11.1, C12.1, C13.1, C14.1, C15.1, C16.1, C17.1, C18.1, C19.1, C20.1, C21.1, C22.1, C23.1, C24.1, C25.1, C26.1, C27.1, C28.1, C29.1, C30.1, C31.1, C32.1, C33.1, C34.1, C35.1, C36.1, C37.1, C40.2, C41.2, C42.2, D1.3 (VSS), D2.3 (VSS), D3.3 (VSS), D4.3 (VSS), D5.3 (VSS), D6.3 (VSS), D7.3 (VSS), D8.3 (VSS), D9.3 (VSS), D10.3 (VSS), D11.3 (VSS), D12.3 (VSS), D13.3 (VSS), D14.3 (VSS), D15.3 (VSS), D16.3 (VSS), D17.3 (VSS), D18.3 (VSS), D19.3 (VSS), D20.3 (VSS), D21.3 (VSS), D22.3 (VSS), D23.3 (VSS), D24.3 (VSS), D26.3 (K2), J1.A12 (GND), J1.B12 (GND), J1.SH (SHIELD), J2.3, J3.2 (-), JP5.2 (B), JP6.2 (B), JP7.2 (B), MK1.1 (-), R6.1, R10.1, R11.1, R13.1, R14.1, R18.1, R19.1, SW1.3 (C), SW2.2, TP3.1 (1_1), U1.1 (GND), U1.2 (GND), U1.11 (GND), U1.14 (GND), U1.36 (GND), U1.37 (GND), U1.38 (GND), U1.39 (GND), U1.40 (GND), U1.41 (GND), U1.42 (GND), U1.43 (GND), U1.44 (GND), U1.45 (GND), U1.46 (GND), U1.47 (GND), U1.48 (GND), U1.49 (GND), U1.50 (GND), U1.51 (GND), U1.52 (GND), U1.53 (GND), U2.4 (V-), U3.2 (GND), U4.2 (V_{SS}), U5.4 (VSS)
unnamed: C38.1, R7.1, R9.2, U2.1
unnamed: C39.1, R7.2
unnamed: D1.2 (DOUT), D2.4 (DIN)
unnamed: D2.2 (DOUT), D3.4 (DIN), JP1.2 (B), JP2.1 (A)
unnamed: D3.2 (DOUT), D4.4 (DIN)
unnamed: D4.2 (DOUT), D5.4 (DIN), JP2.2 (B), JP3.1 (A)
unnamed: D5.2 (DOUT), D6.4 (DIN)
unnamed: D6.2 (DOUT), D7.4 (DIN), JP3.2 (B), JP4.1 (A)
unnamed: D7.2 (DOUT), D8.4 (DIN)
unnamed: D8.2 (DOUT), D9.4 (DIN), JP4.2 (B)
unnamed: D9.2 (DOUT), D10.4 (DIN)
unnamed: D10.2 (DOUT), D11.4 (DIN)
unnamed: D11.2 (DOUT), D12.4 (DIN)
unnamed: D12.2 (DOUT), D13.4 (DIN)
unnamed: D13.2 (DOUT), D14.4 (DIN)
unnamed: D14.2 (DOUT), D15.4 (DIN)
unnamed: D15.2 (DOUT), D16.4 (DIN)
unnamed: D16.2 (DOUT), D17.4 (DIN)
unnamed: D17.2 (DOUT), D18.4 (DIN)
unnamed: D18.2 (DOUT), D19.4 (DIN)
unnamed: D19.2 (DOUT), D20.4 (DIN)
unnamed: D20.2 (DOUT), D21.4 (DIN)
unnamed: D21.2 (DOUT), D22.4 (DIN)
unnamed: D22.2 (DOUT), D23.4 (DIN)
unnamed: D23.2 (DOUT), D24.4 (DIN)
unnamed: C7.2, D25.1 (K), Q1.2 (S), SW1.1 (A), U3.1 (IN)
unnamed: D26.1 (A2), R16.1
unnamed: D26.4 (K1), R15.2
unnamed: J1.A5 (CC1), R19.2
unnamed: J1.B5 (CC2), R18.2
unnamed: C5.1, MK1.2 (+), R8.2
unnamed: R3.1, U1.5 (GPIO2/ADC1_CH2)
unnamed: R4.1, U1.22 (GPIO8)
unnamed: C6.2, R5.1, R6.2, U2.3 (+), U2.5 (+)
unnamed: C5.2, C38.2, R9.1, U2.2 (-)
unnamed: R10.2, R11.2, U4.5 (PROG)
unnamed: R15.1, R16.2, U4.1 (STAT)
VBUS: C37.2, D25.2 (A), D26.2 (A1), J1.A9 (VBUS), J1.B9 (VBUS), Q1.1 (G), R14.2, U4.4 (V_{DD})

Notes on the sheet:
Display
Actual number of LEDs is configurable by: * shorting JP1 to JP4 to skip each of the first four pairs * shorting JP5 to JP7 to define the total number of LEDs with a minimum of 10 and enabling the next 2, 4, or 8 pairs, respectively. For example: * Shorting JP1, JP2, and JP6 will skip LEDs D1..D4 an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
Audio
MCU
Power

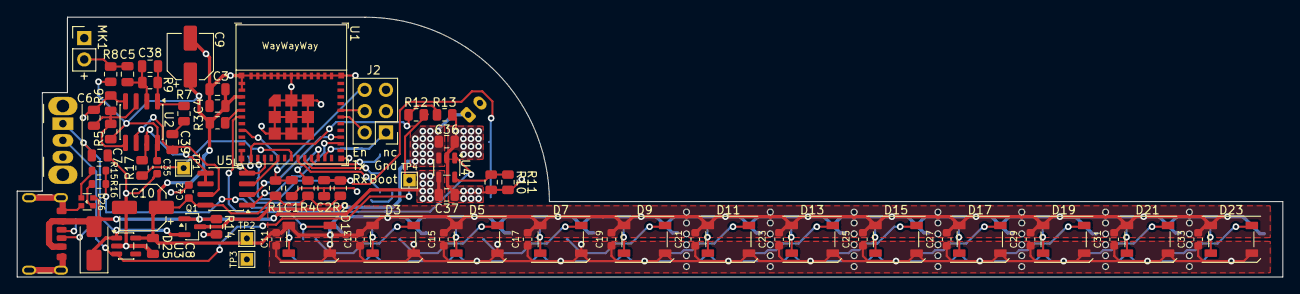
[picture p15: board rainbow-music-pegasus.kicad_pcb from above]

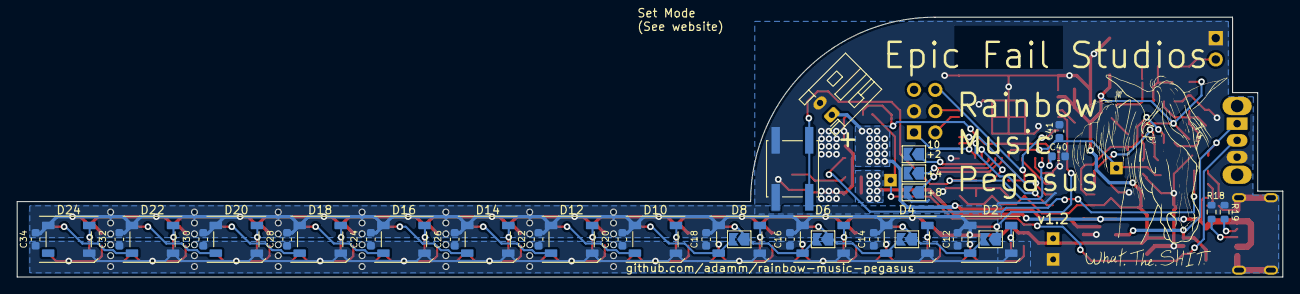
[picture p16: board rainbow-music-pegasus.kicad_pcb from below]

Board: 2 copper layers, 151.0 x 31.0 mm, 110 parts (37 on the bottom side), 58 nets.

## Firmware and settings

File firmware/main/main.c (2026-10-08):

/*
 * SPDX-FileCopyrightText: 2022-2023 Espressif Systems (Shanghai) CO LTD
 *
 * SPDX-License-Identifier: Apache-2.0
 */
#include <stdio.h>
#include <stdlib.h>
#include <string.h>
#include <math.h>

#include "esp_dsp.h"
#include "esp_log.h"
#include "esp_system.h"
#include "esp_timer.h"
#include "freertos/FreeRTOS.h"
#include "freertos/task.h"
#include "soc/soc_caps.h"


#include "battery.h"
#include "config.h"
#include "digipot.h"
#include "fft.h"
#include "leds.h"
#include "mic.h"

const static char *TAG = "main";



#define N_SAMPLES _config_total_samples
// Each frame overlaps the one before by half, so the LEDs update every half
// frame, every 15.4 ms with 24 LEDs in pattern C.  Updating only once a frame
// sampled a held note's level too slowly to follow quick changes in it, such
// as close partials beating, and turned them into a slow flutter.
#define N_HOP (N_SAMPLES / 2)
// leds_display() only shows the lowest bins, three per pair of LEDs in pattern
// A and three per LED in the others.
#define N_DISPLAYED_BINS config_displayed_bins()

// Each bin is converted to the amplitude, in mV at the ADC, of a sine wave that
// would produce it, so the LEDs behave the same whatever the frame size.  Bins
// under the noise floor stay dark so amp and ADC hiss doesn't flicker the LEDs,
// and bins at full scale light their LED at full brightness.  Full scale is well
// under the ADC's ~750 mV of headroom, leaving room for peaks across many bins.
#define FFT_NOISE_FLOOR_MV 8.5f
#define FFT_FULL_SCALE_MV  150.0f

#define DB_TO_RATIO(db) powf(10, (db) / 20)

// Each bin's floor is the level of the room's background sound in it, such as a
// crowd talking, and the bin lights only once it's FLOOR_MARGIN_DB over that.
// The floor rises slowly while the bin is louder than it and falls three times
// as fast while it's quieter, so it settles where the bin is quieter than it a
// quarter of the time.  A crowd never goes quiet, so the floor sits on it, but
// beats are loud for much less than three quarters of the time and stand out.
// Anything held steady is learned too, so a note held 20 dB over the threshold
// fades out in about 20 seconds.  Noise in a bin jumps around from frame to
// frame, and reaches the margin over its quietest quarter in only 1 to 2% of
// frames.
#define FLOOR_RISE_DB_PER_S  1.0f
#define FLOOR_FALL_DB_PER_S  3.0f
#define FLOOR_MARGIN_DB      12.0f
// Below this the threshold would be under FFT_NOISE_FLOOR_MV anyway, so the
// floor stops here, ready to learn a crowd from where it starts to matter.
#define FLOOR_LOWEST_MV      (FFT_NOISE_FLOOR_MV / DB_TO_RATIO(FLOOR_MARGIN_DB))
// While the mic settles at power-on, the floor learns the room this many times
// faster, so it can climb 45 dB in the 3 seconds.
#define FLOOR_SETTLE_SPEEDUP 15.0f
// How often to log how many of the shown bins' floors went up or down, to watch
// them learn a room.  A floor counts as moved once it's changed by more than
// FLOOR_LOG_MOVED_DB since the last log, so a settled floor's jitter doesn't.
#define FLOOR_LOG_US         1000000
#define FLOOR_LOG_MOVED_DB   0.5f

// Once the sound in a bin drops, its LED fades to about a third (1/e) of its
// brightness in this time.  Fading by a fraction rather than a fixed step keeps
// dim LEDs from blinking out, so quiet music doesn't flicker.  Rises show
// immediately.
#define LED_DECAY_US 150000

// How often to check the battery during the light show.  Each check delays the
// next frame by up to a frame, which is too brief and rare to notice.
#define BATTERY_CHECK_US 10000000

// How often to log how long the light show takes to process a frame, and how
// many hops of new samples the mic dropped because the frame before was still
// being processed.  The loop keeps up while processing a frame takes less time
// than recording a hop.
#define FRAME_LOG_US         1000000

// Each shown bin's floor at the last floor log, and when that was, 0 for never.
static float floor_logged[CONFIG_MAX_LEDS * 3];
static int64_t floor_logged_us = 0;

// Whether the samples kept from the last frame are out of date, so the next
// frame must be read whole: at power-on, and after the mic pauses.  And
// mic_frames_dropped() after the last frame was read, as a dropped hop leaves
// a gap after them too.
static bool frame_stale = true;
static uint32_t frame_dropped = 0;

// The time spent on each step of the frames since the last frame log, in µs.
static struct {
    int frames;
    int64_t read_us;       // converting samples to mV, not waiting for them
    int64_t window_us;     // removing DC and applying the window
    int64_t fft_us;
    int64_t magnitude_us;
    int64_t busy_us;       // the whole frame, except waiting for samples
    int64_t max_busy_us;
    int64_t frame_end_us;  // when the last frame ended
    int64_t waited_us;     // mic_time_waited_us() then
    uint32_t dropped;      // mic_frames_dropped() at the last log
    int64_t logged_us;
} frame_stats;


// Add the time since *since to *total_us, and move *since on to now.
static void time_step(int64_t* total_us, int64_t* since)
{
    int64_t now = esp_timer_get_time();
    *total_us += now - *since;
    *since = now;
}


// Read a hop of samples from the mic into the end of the frame in voltages,
// after the newest samples of the last frame, and put the shown bins' levels,
// in mV, in vReal.  The bins past them are left as they were, as nothing uses
// them.
// Then let the mic adjust its sensitivity to fit the LEDs: too loud if the ADC
// clipped or the brightest LED would be at full brightness, too quiet if the
// loudest bin is under a quarter of that.  The 12 dB gap between the two is
// several sensitivity steps wide, so the gain settles instead of hunting.
// Returns how much the mic's gain changed, as a ratio.
static float read_spectrum(int* voltages, float* vReal)
{
    float peak = 0;
    int64_t step_start = esp_timer_get_time();
    int64_t waited = mic_time_waited_us();
    bool clipped = false;
    if (frame_stale || mic_frames_dropped() != frame_dropped) {
        for (int start = 0; start < N_SAMPLES; start += N_HOP)
            clipped |= mic_read_frame(voltages + start, N_HOP);
        frame_stale = false;
    } else {
        memmove(voltages, voltages + N_HOP, (N_SAMPLES - N_HOP) * sizeof(int));
        clipped = mic_read_frame(voltages + N_SAMPLES - N_HOP, N_HOP);
    }
    frame_dropped = mic_frames_dropped();
    frame_stats.read_us -= mic_time_waited_us() - waited;
    time_step(&frame_stats.read_us, &step_start);

    fft_load(voltages);
    time_step(&frame_stats.window_us, &step_start);
    fft_compute();
    time_step(&frame_stats.fft_us, &step_start);
    int bins = N_DISPLAYED_BINS;
    fft_magnitudes(vReal, bins);
    time_step(&frame_stats.magnitude_us, &step_start);

    for (int i = 0; i < bins; i++) {
        if (vReal[i] > peak)
            peak = vReal[i];
    }

    return mic_sensitivity_update(clipped || peak >= FFT_FULL_SCALE_MV, peak < FFT_FULL_SCALE_MV / 4);
}


// Learn each shown bin's floor in vFloor from this frame's bins in vReal, in
// mV, elapsed_us after the last frame, and speedup times faster than normal.
// Then follow the mic's gain, which changes by gain_change within a frame or
// so.
static void track_floor(const float* vReal, float* vFloor, float gain_change, int64_t elapsed_us, float speedup)
{
    float seconds = speedup * elapsed_us / 1e6f;
    float rise = DB_TO_RATIO(FLOOR_RISE_DB_PER_S * seconds) * gain_change;
    float fall = DB_TO_RATIO(-FLOOR_FALL_DB_PER_S * seconds) * gain_change;
    int bins = N_DISPLAYED_BINS;

    for (int i = 0; i < bins; i++) {
        vFloor[i] *= vReal[i] > vFloor[i] ? rise : fall;
        if (vFloor[i] < FLOOR_LOWEST_MV)
            vFloor[i] = FLOOR_LOWEST_MV;
    }
}


// Every FLOOR_LOG_US, log how many of the shown bins' floors went up or down.
// Leave out the mic's gain changes, gain_change since the last frame, which
// mic.c logs itself.
static void log_floor(const float* vFloor, float gain_change, int64_t now)
{
    for (int i = 0; i < N_DISPLAYED_BINS; i++)
        floor_logged[i] *= gain_change;

    if (floor_logged_us != 0 && now - floor_logged_us < FLOOR_LOG_US)
        return;

    if (floor_logged_us != 0) {
        float moved = DB_TO_RATIO(FLOOR_LOG_MOVED_DB);
        int up = 0, down = 0;

        for (int i = 0; i < N_DISPLAYED_BINS; i++) {
            if (vFloor[i] > floor_logged[i] * moved)
                up++;
            else if (vFloor[i] < floor_logged[i] / moved)
                down++;
        }
        ESP_LOGI(TAG, "adjusted the floor up on %d bins and down on %d, of %d", up, down, N_DISPLAYED_BINS);
    }

    memcpy(floor_logged, vFloor, N_DISPLAYED_BINS * sizeof(float));
    floor_logged_us = now;
}


// Start timing the light show's frames, from `now`.
static void start_frame_log(int64_t now)
{
    memset(&frame_stats, 0, sizeof(frame_stats));
    frame_stats.frame_end_us = now;
    frame_stats.waited_us = mic_time_waited_us();
    frame_stats.dropped = mic_frames_dropped();
    frame_stats.logged_us = now;
}


// The average of total_us over the frames since the last frame log, in ms.
static float ms_per_frame(int64_t total_us)
{
    return total_us / 1000.0f / frame_stats.frames;
}


// Count a frame of the light show that ended at `now`.  Every FRAME_LOG_US,
// log how long frames took to process, step by step, and how many hops the
// mic dropped.  The rest is the floor, the colours, sending them to the LEDs, the
// battery check and logging.
static void log_frames(int64_t now)
{
    int64_t waited = mic_time_waited_us();
    int64_t busy = now - frame_stats.frame_end_us - (waited - frame_stats.waited_us);

    frame_stats.frames++;
    frame_stats.busy_us += busy;
    if (busy > frame_stats.max_busy_us)
        frame_stats.max_busy_us = busy;
    frame_stats.frame_end_us = now;
    frame_stats.waited_us = waited;

    if (now - frame_stats.logged_us < FRAME_LOG_US)
        return;

    uint32_t dropped = mic_frames_dropped();
    int64_t steps_us = frame_stats.read_us + frame_stats.window_us + frame_stats.fft_us + frame_stats.magnitude_us;
    ESP_LOGI(TAG, "%d frames of %.1f ms, %.1f ms apart, %d dropped, %.1f ms busy each (max %.1f): "
             "read %.1f, window %.1f, FFT %.1f, magnitude %.1f, rest %.1f",
             frame_stats.frames, N_SAMPLES * 1000.0f / _config_sample_freq_hz,
             N_HOP * 1000.0f / _config_sample_freq_hz, (int)(dropped - frame_stats.dropped),
             ms_per_frame(frame_stats.busy_us), frame_stats.max_busy_us / 1000.0f,
             ms_per_frame(frame_stats.read_us), ms_per_frame(frame_stats.window_us),
             ms_per_frame(frame_stats.fft_us), ms_per_frame(frame_stats.magnitude_us),
             ms_per_frame(frame_stats.busy_us - steps_us));

    start_frame_log(now);
}


// Replace each shown bin in vReal with its LED brightness, and set colours
// from it.  A bin lights once it's FLOOR_MARGIN_DB over its floor in vFloor,
// and never under FFT_NOISE_FLOOR_MV.  vDecay holds each LED's brightness from
// the last frame, elapsed_us ago: louder bins show immediately, and quieter
// ones fade from there.
static void spectrum_to_colours(float* vReal, const float* vFloor, float* vDecay, uint8_t* colours, int64_t elapsed_us)
{
    float decay = expf(-(float)elapsed_us / LED_DECAY_US);
    float margin = DB_TO_RATIO(FLOOR_MARGIN_DB);
    int bins = N_DISPLAYED_BINS;

    for (int i = 0; i < bins; i++) {
        // Scale each bin from its threshold up to full scale to an LED
        // brightness from 0 to 250, so music over a noisy room can still reach
        // full brightness.
        float threshold = fmaxf(FFT_NOISE_FLOOR_MV, margin * vFloor[i]);
        if (vReal[i] <= threshold)
            vReal[i] = 0;
        else if (vReal[i] >= FFT_FULL_SCALE_MV)
            vReal[i] = 250;
        else
            vReal[i] = (vReal[i] - threshold) * 250 / (FFT_FULL_SCALE_MV - threshold);

        if (vReal[i] > vDecay[i])
            vDecay[i] = vReal[i];
        else
            vDecay[i] *= decay;

        colours[i] = (uint8_t)vDecay[i];
    }
}


// Read the battery, and have the LEDs warn if it's low.  ADC1 can't take a
// battery reading while it samples the mic continuously, so pause the mic for
// it.  The samples kept from the last frame end before the pause, so read the
// next frame whole.
static void read_battery(void)
{
    mic_pause();
    leds_show_low_battery(battery_check());
    mic_resume();
    frame_stale = true;
}


void app_main(void)
{
    config_init();
    int* voltages = malloc(sizeof(int) * _config_total_samples);
    float* vReal = malloc(sizeof(float) * _config_total_samples);
    float* vDecay = malloc(sizeof(float) * _config_total_samples);
    float* vFloor = malloc(sizeof(float) * _config_total_samples);
    uint8_t* colours = malloc(sizeof(uint8_t) * _config_total_samples);

    bzero(voltages, sizeof(int) * _config_total_samples);
    bzero(vReal, sizeof(float) * _config_total_samples);
    bzero(vDecay, sizeof(float) * _config_total_samples);
    bzero(colours, sizeof(uint8_t) * _config_total_samples);
    for (int i = 0; i < _config_total_samples; i++)
        vFloor[i] = FLOOR_LOWEST_MV;

    digipot_init();
    battery_init();
    // The mic isn't sampling yet, so ADC1 is free for the first battery reading.
    leds_show_low_battery(battery_check());
    mic_init(N_HOP);
    leds_init();
    leds_scanning_start();
    fft_init(N_SAMPLES);

    uint64_t start_settle_time = esp_timer_get_time();
    int64_t last_frame_time = start_settle_time;

    // Give the mic a few seconds to settle its sensitivity, and the floor to
    // learn the room, before the light show starts.
    ESP_LOGI(TAG, "Settling mic sensitivity...");
    while (esp_timer_get_time()-start_settle_time < 3000000) {
        float gain_change = read_spectrum(voltages, vReal);
        int64_t now = esp_timer_get_time();
        track_floor(vReal, vFloor, gain_change, now - last_frame_time, FLOOR_SETTLE_SPEEDUP);
        log_floor(vFloor, gain_change, now);
        last_frame_time = now;
    }
    ESP_LOGI(TAG, "Finished settling mic sensitivity...");
    leds_scanning_stop();

    // Begin light show
    int64_t last_battery_time = esp_timer_get_time();
    start_frame_log(last_battery_time);
    while (1) {
        float gain_change = read_spectrum(voltages, vReal);

        // Base the floor and the fade on the time since the last frame, so
        // their speed doesn't depend on the frame size or on frames the driver
        // dropped.
        int64_t now = esp_timer_get_time();
        track_floor(vReal, vFloor, gain_change, now - last_frame_time, 1);
        log_floor(vFloor, gain_change, now);
        spectrum_to_colours(vReal, vFloor, vDecay, colours, now - last_frame_time);
        last_frame_time = now;

        // printf("R: ");
        // for (int i = 0; i < 16; i++) {
        //     printf("%0.1f ", vReal[i]);
        // }
        // printf("\nD: ");
        // for (int i = 0; i < 16; i++) {
        //     printf("%0.1f ", vDecay[i]);
        // }
        // printf("\n");
        // ESP_LOGI(TAG, "fft");
        // dsps_view(vReal, N_SAMPLES, 64, 10, 0, 255, '-');

        leds_display(colours, N_DISPLAYED_BINS);

        if (now - last_battery_time >= BATTERY_CHECK_US) {
            read_battery();
            last_battery_time = now;
        }

        log_frames(esp_timer_get_time());
    }

    mic_stop();
    battery_stop();
    digipot_stop();
}

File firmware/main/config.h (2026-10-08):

#pragma once

#include "sdkconfig.h"

#ifdef CONFIG_IDF_TARGET_ESP32C3
#define CONFIG_MIC_UNIT                ADC_UNIT_1
#define CONFIG_MIC_CHANNEL             ADC_CHANNEL_4   // GPIO 4
#define CONFIG_BATTERY_UNIT            ADC_UNIT_1
#define CONFIG_BATTERY_CHANNEL         ADC_CHANNEL_0   // GPIO 0
#else
#error "Only ESP32C3 is tested/supported. The original ESP32 won't work due to how audio is read. YMMV for other ESP32 models."
#endif
#define CONFIG_MIC_ATTEN               ADC_ATTEN_DB_12
#define CONFIG_BATTERY_ATTEN           ADC_ATTEN_DB_12

// The LEDs show 0 Hz up to this frequency whatever their count, shared equally
// between the pairs, so more LEDs show it in finer steps.  config_init() picks
// the sample rate to fit.  2344 Hz keeps a 10-LED board sampling at about
// 10 kHz, as before.  Much above 4 kHz, the mic's anti-aliasing filter (R17 and
// C41, -3 dB at 4.8 kHz) dims the highest LEDs.
#define CONFIG_LEDS_TOP_FREQ_HZ        2344

// How leds_display() lays the FFT bins out on the LEDs' colour channels.  Each
// pair of LEDs is the same place on the right (even index) and left wing.
typedef enum {
    // Three bins per pair, lowest first: green, red, blue on the right LED,
    // and the same bins on the left with the channels rotated.
    CONFIG_PATTERN_A,
    // One bin per channel, six per pair, lowest first: the right then left
    // LED's red, then their green, then their blue.
    CONFIG_PATTERN_B,
    // One bin per channel: the lowest third light every LED's red in strip
    // order, the middle third their green, and the top third their blue.
    CONFIG_PATTERN_C,
} config_pattern_t;

// The pattern at power-on, the starting value of _config_pattern, which
// config_init() sizes the FFT for.  Patterns B and C show twice as many bins as
// A, so they use FFT sizes twice as large to keep the same sample rates and
// frequency range.  Their bins are half as wide, and their frames twice as
// long, up to 30.7 ms with 24 LEDs.
#define CONFIG_LEDS_PATTERN            CONFIG_PATTERN_C

#define CONFIG_GPIO_RGB_DATA           3

#define CONFIG_GPIO_TOTAL_LEDS_ADD_2   7
#define CONFIG_GPIO_TOTAL_LEDS_ADD_4   6
#define CONFIG_GPIO_TOTAL_LEDS_ADD_8   5

#define CONFIG_MIN_LEDS               10
#define CONFIG_MAX_LEDS               24

#define CONFIG_GPIO_DIGIPOT_CS        18
#define CONFIG_GPIO_DIGIPOT_MOSI      10
#define CONFIG_GPIO_DIGIPOT_CLK       19

extern uint8_t _config_total_leds;
extern config_pattern_t _config_pattern;
extern uint16_t _config_total_samples;
extern uint32_t _config_sample_freq_hz;

void config_init();
uint16_t config_displayed_bins(void);

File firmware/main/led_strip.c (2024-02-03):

/*
 * SPDX-FileCopyrightText: 2021-2022 Espressif Systems (Shanghai) CO LTD
 *
 * SPDX-License-Identifier: Unlicense OR CC0-1.0
 */
#include <string.h>
#include "freertos/FreeRTOS.h"
#include "freertos/task.h"
#include "esp_log.h"
#include "driver/rmt_tx.h"
#include "led_strip_encoder.h"


#define RMT_LED_STRIP_RESOLUTION_HZ 10000000 // 10MHz resolution, 1 tick = 0.1us (led strip needs a high resolution)
#define RMT_LED_STRIP_GPIO_NUM      3

#define EXAMPLE_LED_NUMBERS         11
#define EXAMPLE_CHASE_SPEED_MS      100

static const char *TAG = "example";

static uint8_t led_strip_pixels[EXAMPLE_LED_NUMBERS * 3];

/**
 * @brief Simple helper function, converting HSV color space to RGB color space
 *
 * Wiki: https://en.wikipedia.org/wiki/HSL_and_HSV
 *
 */
void led_strip_hsv2rgb(uint32_t h, uint32_t s, uint32_t v, uint32_t *r, uint32_t *g, uint32_t *b)
{
    h %= 360; // h -> [0,360]
    uint32_t rgb_max = v * 2.55f;
    uint32_t rgb_min = rgb_max * (100 - s) / 100.0f;

    uint32_t i = h / 60;
    uint32_t diff = h % 60;

    // RGB adjustment amount by hue
    uint32_t rgb_adj = (rgb_max - rgb_min) * diff / 60;

    switch (i) {
    case 0:
        *r = rgb_max;
        *g = rgb_min + rgb_adj;
        *b = rgb_min;
        break;
    case 1:
        *r = rgb_max - rgb_adj;
        *g = rgb_max;
        *b = rgb_min;
        break;
    case 2:
        *r = rgb_min;
        *g = rgb_max;
        *b = rgb_min + rgb_adj;
        break;
    case 3:
        *r = rgb_min;
        *g = rgb_max - rgb_adj;
        *b = rgb_max;
        break;
    case 4:
        *r = rgb_min + rgb_adj;
        *g = rgb_min;
        *b = rgb_max;
        break;
    default:
        *r = rgb_max;
        *g = rgb_min;
        *b = rgb_max - rgb_adj;
        break;
    }
}

void app_main(void)
{
    uint32_t red = 0;
    uint32_t green = 0;
    uint32_t blue = 0;
    uint16_t hue = 0;
    uint16_t start_rgb = 0;

    ESP_LOGI(TAG, "Create RMT TX channel");
    rmt_channel_handle_t led_chan = NULL;
    rmt_tx_channel_config_t tx_chan_config = {
        .clk_src = RMT_CLK_SRC_DEFAULT, // select source clock
        .gpio_num = RMT_LED_STRIP_GPIO_NUM,
        .mem_block_symbols = 64, // increase the block size can make the LED less flickering
        .resolution_hz = RMT_LED_STRIP_RESOLUTION_HZ,
        .trans_queue_depth = 4, // set the number of transactions that can be pending in the background
    };
    ESP_ERROR_CHECK(rmt_new_tx_channel(&tx_chan_config, &led_chan));

    ESP_LOGI(TAG, "Install led strip encoder");
    rmt_encoder_handle_t led_encoder = NULL;
    led_strip_encoder_config_t encoder_config = {
        .resolution = RMT_LED_STRIP_RESOLUTION_HZ,
    };
    ESP_ERROR_CHECK(rmt_new_led_strip_encoder(&encoder_config, &led_encoder));

    ESP_LOGI(TAG, "Enable RMT TX channel");
    ESP_ERROR_CHECK(rmt_enable(led_chan));

    ESP_LOGI(TAG, "Start LED rainbow chase");
    rmt_transmit_config_t tx_config = {
        .loop_count = 0, // no transfer loop
    };
    while (1) {
        for (int i = 0; i < 3; i++) {
            for (int j = i; j < EXAMPLE_LED_NUMBERS; j += 3) {
                // Build RGB pixels
                hue = j * 360 / EXAMPLE_LED_NUMBERS + start_rgb;
                led_strip_hsv2rgb(hue, 100, 100, &red, &green, &blue);
                led_strip_pixels[j * 3 + 0] = green;
                led_strip_pixels[j * 3 + 1] = blue;
                led_strip_pixels[j * 3 + 2] = red;
            }
            // Flush RGB values to LEDs
            ESP_ERROR_CHECK(rmt_transmit(led_chan, led_encoder, led_strip_pixels, sizeof(led_strip_pixels), &tx_config));
            ESP_ERROR_CHECK(rmt_tx_wait_all_done(led_chan, portMAX_DELAY));
            vTaskDelay(pdMS_TO_TICKS(EXAMPLE_CHASE_SPEED_MS));
            memset(led_strip_pixels, 0, sizeof(led_strip_pixels));
            ESP_ERROR_CHECK(rmt_transmit(led_chan, led_encoder, led_strip_pixels, sizeof(led_strip_pixels), &tx_config));
            ESP_ERROR_CHECK(rmt_tx_wait_all_done(led_chan, portMAX_DELAY));
            //vTaskDelay(pdMS_TO_TICKS(EXAMPLE_CHASE_SPEED_MS));
        }
        start_rgb += 60;
    }
}

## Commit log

2023-09-10 Include blender build files of the design
    [pegasus.blend, pegasus.stl]
2023-10-15 Double the size of the horse, increase the total neopixel LEDs to 21
    [pegasus.blend, pegasus.stl]
2024-02-03 Initial commit to PCB design
    [rainbow-music-pegasus.kicad_pcb, rainbow-music-pegasus.kicad_sch]
2024-02-04 Begin schematic and PCB layout
    [rainbow-music-pegasus.kicad_pcb, rainbow-music-pegasus.kicad_sch]
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2024-02-07 Working PCB design using esp32c3 and 20 ws2812b LEDs -- BOM pending validation
    [rainbow-music-pegasus.kicad_pcb, rainbow-music-pegasus.kicad_sch]
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2024-02-10 Finalize PCB layout for first production run
    [rainbow-music-pegasus.kicad_pcb, rainbow-music-pegasus.kicad_sch]
2024-02-10 Added a few test points for power. Committing gerbers
    [rainbow-music-pegasus-B_Cu.gbr, rainbow-music-pegasus-B_Mask.gbr, rainbow-music-pegasus-B_Paste.gbr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]
2024-02-11 Added Altivo cartoon to silkscreen, jumpers for configuring total LEDs installed
    [rainbow-music-pegasus-B_Cu.gbr, rainbow-music-pegasus-B_Mask.gbr, rainbow-music-pegasus-B_Paste.gbr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]
2024-02-12 Missed a decoupling capacitor at U2; added as C35
    [rainbow-music-pegasus-B_Cu.gbr, rainbow-music-pegasus-B_Mask.gbr, rainbow-music-pegasus-B_Paste.gbr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]
2024-02-13 Allow for configurable sample rate (using JP5, JP6, JP7) and add sound calibration routine (to remove ambient noise from sound analysis)
    [config.c, config.h, main.c]
2024-02-14 Footprint verification done, ready for first production run!
    [rainbow-music-pegasus-B_Cu.gbr, rainbow-music-pegasus-B_Mask.gbr, rainbow-music-pegasus-B_Paste.gbr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]
2024-02-14 Snapshots of ths BOM, Schematics; added license and readme starter.
    [bom.csv, rainbow-music-pegasus.kicad_sch]
2024-02-17 Added a simple scanning effect on the lights while calibrating light show to background noise
    [leds.c, main.c]
2024-02-18 Snapshot the completed pegasus design w/ preliminary placement of the PCB within
    [pcb.scad, pcb.stl, pegasus-extruded.blend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]
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2024-02-19 Tune the placement of the PCB within the Pegasus.
    [pcb.scad, pcb.stl, pegasus.blend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]
2024-03-02 Created a solder stencil mount to hold the PCB level with components already installed on underside
    [pcb.scad, pcb.stl, stencil-mount.scad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]
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2024-03-24 Transition from UltiMarker Cura to PrusaSlicer; other various cleanups so the PCB fits in the pegasus design
    Cura couldn't handle some edges resulting in several mis-prints.
    [pcb.scad, pcb.stl, pegasus.3mf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]
2024-03-24 Added Battery charging module and a new mode-setting button
    Also found 3d models for the microphone, switch, USB components
    [10118194-0001LF.stp, CMA-4544PF-W.stp, OS102011MA1QN1.stp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]
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2024-03-24 Updated the 3d render snapshot, bom, and gerbers
    [bom.csv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]
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2024-03-24 Increase the size of Altivo's picture on the back silkscreen
    [rainbow-music-pegasus-B_Cu.gbr, rainbow-music-pegasus-B_Mask.gbr, rainbow-music-pegasus-B_Paste.gbr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]
2024-03-24 Updated schematics.pdf to v1.1 design, link to KiCanvas
    [rainbow-music-pegasus.kicad_pcb]
2024-03-25 Update the PCB template to include the arc, new usb placement
    [pcb.scad, pcb.stl, stencil-mount.stl]
2024-03-29 Round out the ground fill zone using an arc margin
    Looks much nicer than eyeballing the fill zone into an arc-like shape by
    point
    [rainbow-music-pegasus-B_Cu.gbr, rainbow-music-pegasus-B_Mask.gbr, rainbow-music-pegasus-B_Paste.gbr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]
2024-04-01 Minor updates from feedback
    * Move the WayWayWay to be underneith U1, replaced "Antenna Area"
    * Added solderpaste to thru-holes on J1, makes the Micro-USB jack more secure
    [rainbow-music-pegasus-B_Cu.gbr, rainbow-music-pegasus-B_Mask.gbr, rainbow-music-pegasus-B_Paste.gbr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]
2024-04-08 Add on a digital potentiometer and a dual-channel amp to dynamically capture quiet or loud music
    Includes major realignment of entire top-left corner, chip changes,
    rerouting traces, etc.
    [rainbow-music-pegasus-B_Cu.gbr, rainbow-music-pegasus-B_Mask.gbr, rainbow-music-pegasus-B_Paste.gbr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]
2024-05-11 Updated gerbers, schematics, BOM to match recent pcb layout updates
    [bom.csv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]
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2026-03-27 Minor corrections for the pcb stl negative, and
    * Corrected the rounded edge to be ⌀44mm
    * Removed the indent for the mic from v1.0
    * Corrected the height to 31mm
    [pcb.scad, pcb.stl, rainbow-music-pegasus.kicad_pcb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]
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2026-04-05 Cleaned up the stencil mount for first production run
    [pcb.scad, stencil-mount.scad, stencil-mount.stl]
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2026-04-09 Move TP6 to the DP_Wiper, add TP7 to DP_A and TP8 to MIC feed
    Also fixed the size of all Touchpoints to allow for soldering thru-hole pins
    [rainbow-music-pegasus.kicad_pcb, rainbow-music-pegasus.kicad_sch]
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2026-05-31 Correct the tag for the microphone logs
    [mic.c]
2026-05-31 Claude had some useful suggestions to fix some bugs I didn't even know existed.
    - main.c: Fixed sampling delay — vTaskDelay(pdMS_TO_TICKS(sampling_period_us / 1000))
    performed integer division yielding zero, so samples were taken as
    fast as the MCU could run instead of at 10 kHz. Replaced with
    esp_rom_delay_us(sampling_period_us).
    - mic.c: Fixed crash when ADC calibration is unavailable — mic_read()
    unconditionally passed mic_cali_channel_handle to
    adc_cali_raw_to_voltage(), which crashes if the eFuse is not burnt and
    the handle is NULL. Now checks the handle first and falls back to a
    linear approximation (raw * 3100 / 4095) if uncalibrated.
    - mic.c: Made mic_calibrated s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
    [config.c, leds.c, main.c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]
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2026-05-31 Upgrade to KiCAD 10
    Also resized Altivo to better fit in available back silkscreen area
    [rainbow-music-pegasus.kicad_pcb, rainbow-music-pegasus.kicad_sch]
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2026-09-27 Leverage the digipot to dynamically control the mic sensitivity gain based upon ambient noise.
    The amp dynamically adjusts itself up when there is too low mic input, and down when there is too much.
    [main.c, mic.c]
2026-09-27 Minor changes to the PCB and BOM to better support the digipot and signal
    * Remove C40 (which was shunting the MCP41050 PB0 & PB0, reducing effectiveness)
    * Raise R7 from 470 to 2.2k
    * Raise R17 from 100 to 330
    * Change C41 to a 0.1uF shunt cap to GND placed close to GPIO4
    The R7 is raised 2.2k so the digipot wiper current stays within its +/-1
    mA rating even if the first stage swings rail to rail, and so loud music
    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
    [bom.csv, rainbow-music-pegasus.kicad_pcb, rainbow-music-pegasus.kicad_sch]
2026-09-27 Move the button from GPIO9 to GPIO1
    Eventually the button will be used as a factory reset (remove settings
    like wifi configuration, etc) by holding down on power-on. You cannot
    do that with GPIO9 as that is already used to launch the bootloader on
    power-on.
    Actual button code and functionality still TBD.
    [rainbow-music-pegasus.kicad_pcb, rainbow-music-pegasus.kicad_sch]
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2026-09-27 Measure the battery level from the Switch common pole
    This avoids draining the battery while the power is off, at the cost of
    being unable to measure the battery when USB is plugged in.
    [bom.csv, rainbow-music-pegasus.kicad_sch]
2026-09-27 Run DRC, adjust some cap placements
    Cleaned up errors. Still lots of warnings re: silkscreen violations
    [rainbow-music-pegasus.kicad_pcb]
2026-09-27 Final cleanup of all DRC warnings — added to TODO to upgrade to USB-C
    [rainbow-music-pegasus.kicad_pcb, rainbow-music-pegasus.kicad_sch]
2026-09-27 Minor correction to R9 and C38 as they were speced using the older v1 mic
    Now they're adjusted to support the better AOM-5024P-HD-MB-R microphone.
    BOM updated to match, too.
    [bom.csv, rainbow-music-pegasus.kicad_sch]
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2026-09-28 Replaced the dual 0603 power status LEDs with a LTST-C195KGJRKT
    A little easier to place as the orientation is clear.
    [LTST-C195KGJRKT.step, bom.csv, rainbow-music-pegasus.kicad_pcb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]
2026-09-28 Add battery section to README recommending a 400mAh or larger LiPo
    The MCP73831 charge current is fixed at 200mA by R10 and R11, so a
    400mAh cell keeps the charge rate at or below 0.5C while still allowing
    smaller batteries in smaller horse bodies.
2026-09-28 Converted the power connector from USB-Mini to USB-C
    [bom.csv, rainbow-music-pegasus.kicad_pcb, rainbow-music-pegasus.kicad_sch]
2026-09-29 Convert the battery connector to a flat-mounted SB2-PH-K-S JST connector
    [bom.csv, rainbow-music-pegasus.kicad_pcb, rainbow-music-pegasus.kicad_sch]
2026-09-29 Fixed the J1 footprint to match the USB-C part USB4125-GF-A-0190
    Also added a minor overprinting of solder paste to the USB-C mount posts
    to better adhere to the board.
    [bom.csv, rainbow-music-pegasus.kicad_pcb, rainbow-music-pegasus.kicad_sch]
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2026-09-29 Group the BOM by Value and Footprint
    Oops, all the 0.1uF caps were grouped together by value alone, with
    two different footprints but summing the quantity of each footprint.
    [bom.csv]
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2026-10-01 Base mic auto-gain on LED brightness, not ADC clipping
    The auto-gain now turns the mic down when the brightest LED stays at full
    brightness (or the ADC clips), and up when the loudest displayed FFT bin
    stays under a quarter of that. Previously it waited for ADC clipping, so
    the LEDs saturated to white long before the gain came down. Each FFT bin
    is now converted to mV at the ADC, so brightness no longer depends on the
    frame size: full brightness is 150 mV, and the noise floor is 8.5 mV.
    [main.c, mic.c]
2026-10-01 Adjust the LED decay to be time-based, rather than fixed steps
    [main.c]
2026-10-01 Updated PCB rendering and block diagram for v1.2
    [rainbow-music-pegasus.kicad_pcb]
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2026-10-04 Learn each bin's background floor so music shows over a noisy room
    This is an adaptive floor that changes over time. Consistent background
    sounds like crowds, dull humms, microwaves, vacuums will naturally be
    filtered out. After a few seconds, only the peaks in the sound picked up
    (presumably the music) will show up on the LEDs. As the background noise
    changes shape, the floor is adjusted.
    Log as the floor moves on each bin, to verify tracking and stability.
    [fake_idf.c, main.c, mic.c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]
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2026-10-08 Precompute the window and calibration and process only the shown bins, so the mic no longer drops frames
    [fake_idf.c, main.c, mic.c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]
2026-10-08 Replace the float FFT with a fixed-point one, as the ESP32-C3 has no FPU
    This removes the GPL arduinoFFT code and makes the whole project Apache-2.0
    [main.c, test_main.c]
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
